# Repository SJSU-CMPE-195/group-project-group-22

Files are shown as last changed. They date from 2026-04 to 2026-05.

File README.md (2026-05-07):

# (Neuromorphic) Hardware Neural Network




Neuromorphic computing replicates brain structure and function directly in hardware. Unlike conventional processors, it uses parallel, event-driven processing for greater efficiency. Software-based spiking neural networks (SNNs) appear in autonomous control systems but carry high energy and resource costs. This project implements the SNN as a real analog circuit — a physical, transistor-level network built from discrete components on a breadboard or PCB — so the hardware itself is the AI player.

The fundamental building block is a **3-neuron control unit** implementing the integrate-and-fire model: an excitatory neuron and an inhibitory neuron both feed into a control (output) neuron. The excitatory neuron drives the control neuron to fire; the inhibitory neuron suppresses overfiring and improves signal stability. Each control unit produces one discrete game action. This scheme is scalable — Hit The Zone uses one 3-neuron control unit (one game input), and Pong uses two control units (six neurons total, one control unit per direction).

An ESP32 microcontroller acts as the analog bridge between the neuron circuit and the game software: it injects stimulus voltage into the excitatory neuron in response to game state, reads the control neuron's output voltage via ADC, and streams real-time voltage data to a Java application over USB serial at 115200 baud. The Java application detects neural spikes via rising-edge analysis and translates each spike one-to-one into a discrete game action.

A **Launcher** manages serial connections and serves as the home page for all programs. Two games are supported: **Hit The Zone** (3-neuron, single-channel) and **Pong** (6-neuron, dual-channel — Ch1 controls left, Ch2 controls right). A **Bidirectional Test** diagnostic tool is also included for verifying serial communication and signal integrity.

## Table of Contents

- [Team](#team)
- [Deliverables](#deliverables)
- [Prerequisites](#prerequisites)
- [Hardware](#hardware)
  - [Hardware Revisions](#hardware-revisions)
  - [Schematic](#schematic)
  - [PCB Design](#pcb-design)
  - [Bill of Materials](#bill-of-materials)
  - [Datasheets](#datasheets)
  - [Breadboard Assembly](#breadboard-assembly)
  - [PCB Assembly](#pcb-assembly)
  - [Flashing the ESP32](#flashing-the-esp32)
- [Running the Application](#running-the-application)
- [Configuration](#configuration)
- [Programs](#programs)
  - [Launcher](#launcher)
  - [Hit The Zone](#hit-the-zone)
  - [Pong](#pong)
  - [Bidirectional Test](#bidirectional-test)
  - [Shared Components](#shared-components)
- [Testing](#testing)
- [Project Structure](#project-structure)
- [License](#license)
- [References](#references)

---

## Team

**Project Number:** U32

**Project Title:** Hardware Neural Network

**Advisor:** Eric Vanuska — eric.vanuska@sjsu.edu

| Name | Degree | GitHub | Email |
|---|---|---|---|
| Jonathon Fleming | BSCMPE | [@JellyF02](https://github.com/JellyF02) | jonathon.fleming@sjsu.edu |
| Raymund Mercader | BSSE | [@ray-sjsu](https://github.com/ray-sjsu) | raymund.mercader@sjsu.edu |
| Andrew Neidhart  | BSCMPE | [@andrewneidhart](https://github.com/andrewneidhart) | andrew.neidhart@sjsu.edu  |
| Katrina Weers | BSSE | [@Trina-W](https://github.com/Trina-W) | katrina.weers@sjsu.edu |

[Spring 2026 CMPE Project Expo](https://www.sjsu.edu/cmpe/students/project-expo/2026-spring.php)

[Spring 2026 CMPE Project Roster](https://docs.google.com/spreadsheets/d/1CWvXRMa2uYdF89KqGeZLIvugnG1znIKHWkJCl6HlvxU/edit?gid=0#gid=0)

---

## Deliverables

The project poster provides a full overview of the hardware design, circuit theory, system architecture, and game demonstrations.

U32 Hardware Neural Network Poster

[Download PDF version](docs/deliverables/U32%20Hardware%20Neural%20Network.pdf)

---

## Prerequisites

**Software:**
- [Java JDK 17](https://docs.oracle.com/en/java/javase/17/install/overview-jdk-installation.html)
- [Arduino IDE](https://www.arduino.cc/en/software) (only needed to flash the ESP32)
- [Apache Maven 3.6+](https://maven.apache.org/install.html) and [Git](https://git-scm.com/install/) (only needed to build from source)

**Hardware:**
- ESP32 microcontroller connected via USB/Serial
- Neural network circuit assembled on breadboard or PCB (see [Hardware](#hardware))

---

## Hardware

### Hardware Revisions

Three physical builds were produced over the course of the project. The Breadboard Big, Breadboard Small, and PCB are functionally identical. See the [project poster](#deliverables) for full hardware design details.

| Revision | Form Factor | Neurons | Notes |
|---|---|---|---|
| Breadboard Big | Full-size breadboard | Up to 6 | Initial large-scale prototype |
| Breadboard Small | Half-size breadboard | Up to 6 | Compact verification build |
| PCB (V2) | Custom KiCad PCB | Up to 6 | Production form factor; functionally identical to all breadboard builds |

| Breadboard Big | Breadboard Small vs. PCB |
|---|---|
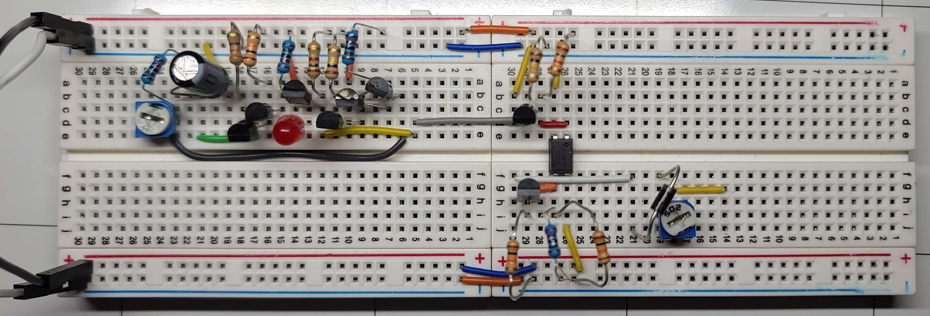
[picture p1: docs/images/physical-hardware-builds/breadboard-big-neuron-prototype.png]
Breadboard Big
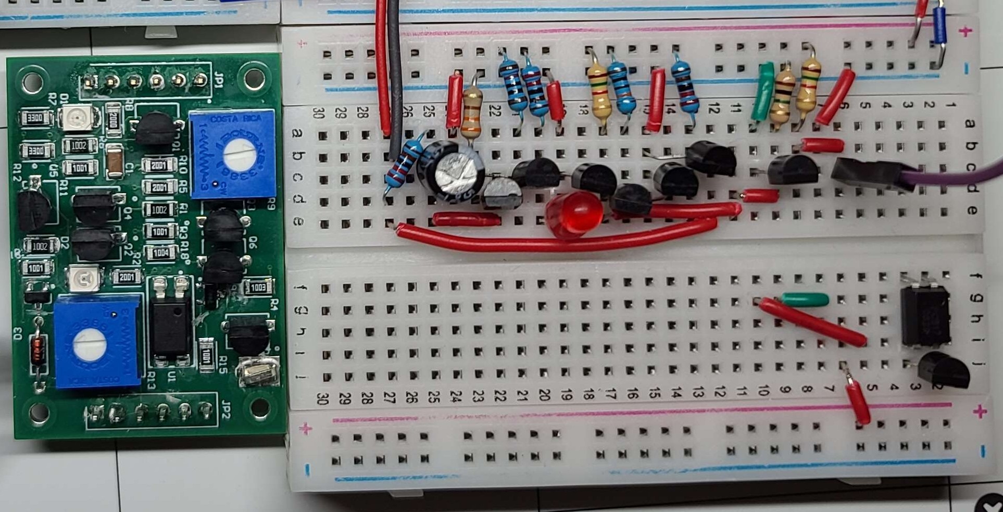
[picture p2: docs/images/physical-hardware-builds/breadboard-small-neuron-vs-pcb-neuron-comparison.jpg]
Breadboard Small vs PCB
|  |  |

| PCB Board | PCB 3D Render |
|---|---|
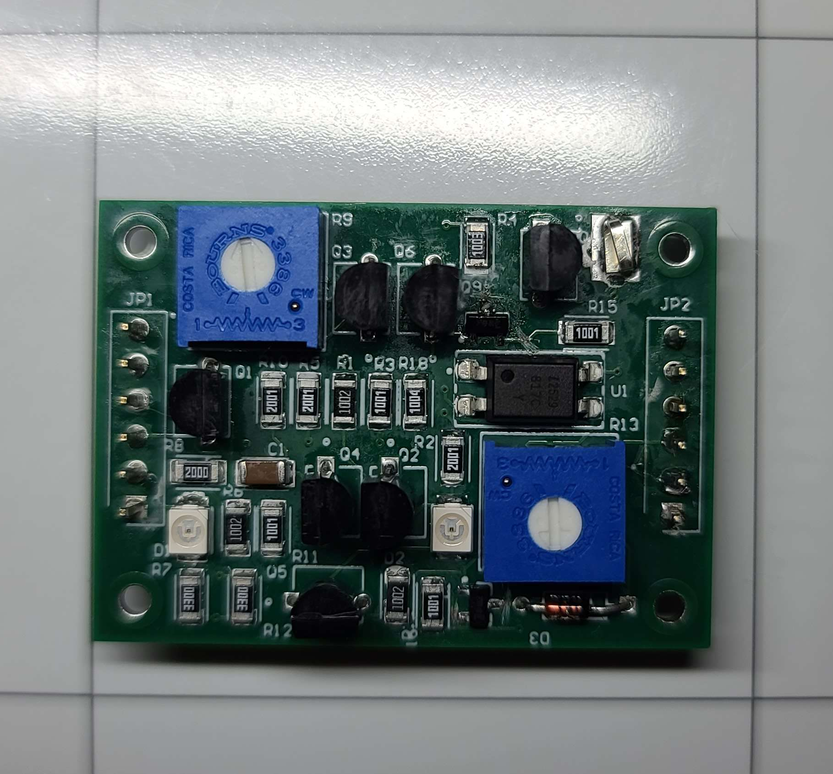
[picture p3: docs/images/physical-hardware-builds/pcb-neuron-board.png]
PCB Board
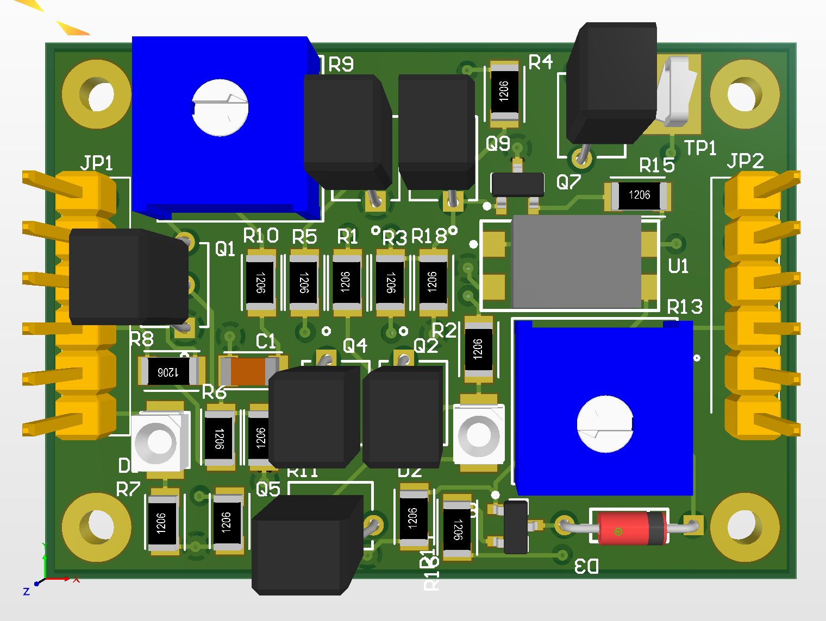
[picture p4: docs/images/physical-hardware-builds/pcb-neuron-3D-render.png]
PCB 3D Render
|  |  |

---

### Schematic

Each neuron in the circuit is built around a **Schmitt trigger** — a comparator with hysteresis. Input voltage charges up slowly (integration), and when it crosses the upper threshold V_UT the output snaps sharply to saturation (the spike). It won't reset until voltage falls below the lower threshold V_LT. The dead band between the two thresholds prevents noise from causing false re-triggers, giving each neuron a clean, stable firing response — directly analogous to a biological action potential [1].

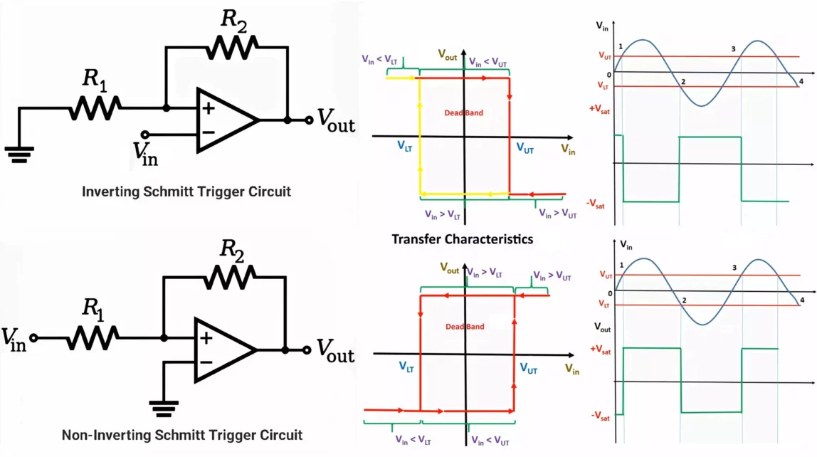
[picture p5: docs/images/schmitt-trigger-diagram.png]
Schmitt Trigger Diagram


**Single Neuron V1** — the initial single-neuron proof-of-concept schematic.

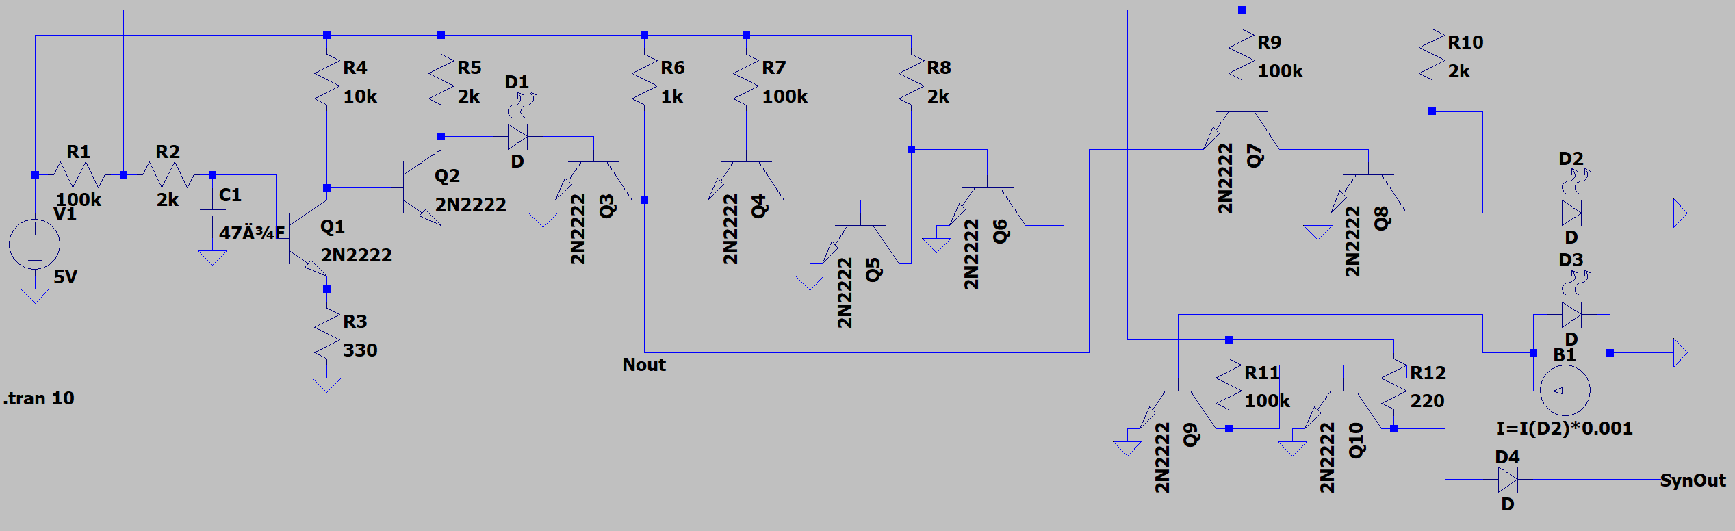
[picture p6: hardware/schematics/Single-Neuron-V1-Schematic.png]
Single Neuron V1 Schematic


Source file: [`hardware/schematics/Single-Neuron-V1-Schematic.asc`](hardware/schematics/Single-Neuron-V1-Schematic.asc) (LTspice)

---

**NeuronSynapseVersion7** — the final 3-neuron design used across all builds.

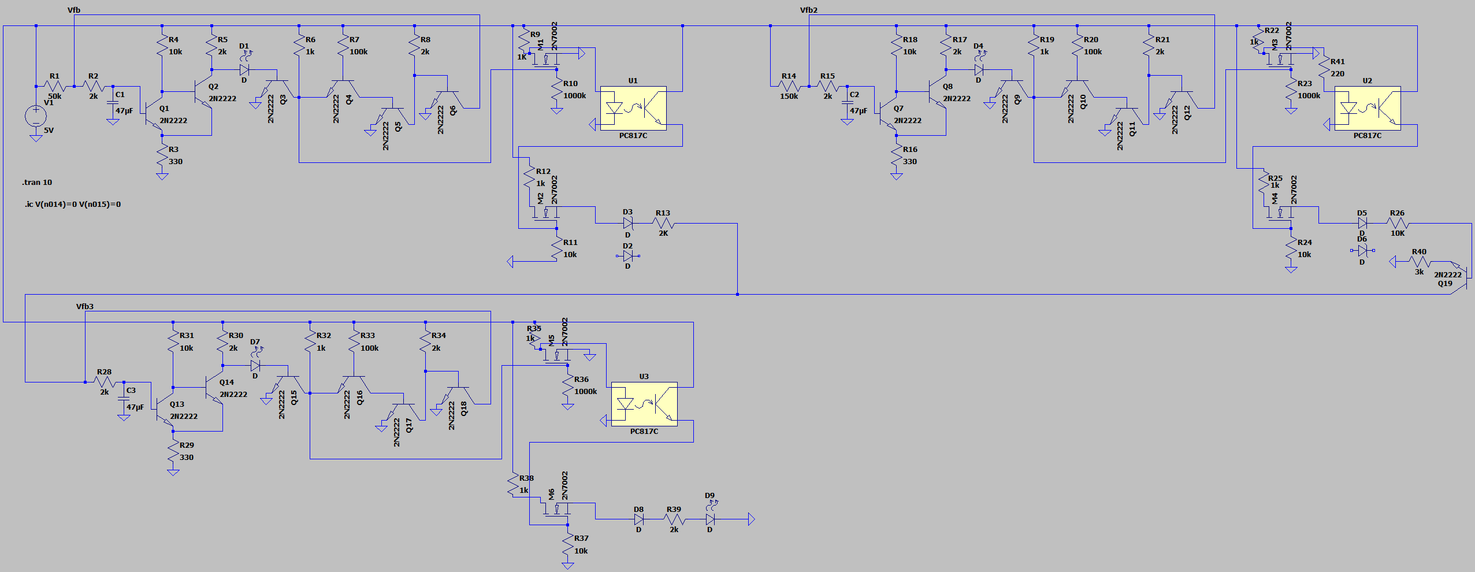
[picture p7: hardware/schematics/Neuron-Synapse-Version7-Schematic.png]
Neuron Synapse Version 7 Schematic


Source files: [`hardware/schematics/Neuron-Synapse-Version7-Schematic.asc`](hardware/schematics/Neuron-Synapse-Version7-Schematic.asc) (LTspice) and [`hardware/schematics/Neuron-Synapse-Version7-Kicad-Schematic.kicad_sch`](hardware/schematics/Neuron-Synapse-Version7-Kicad-Schematic.kicad_sch) (KiCad)

---

### PCB Design

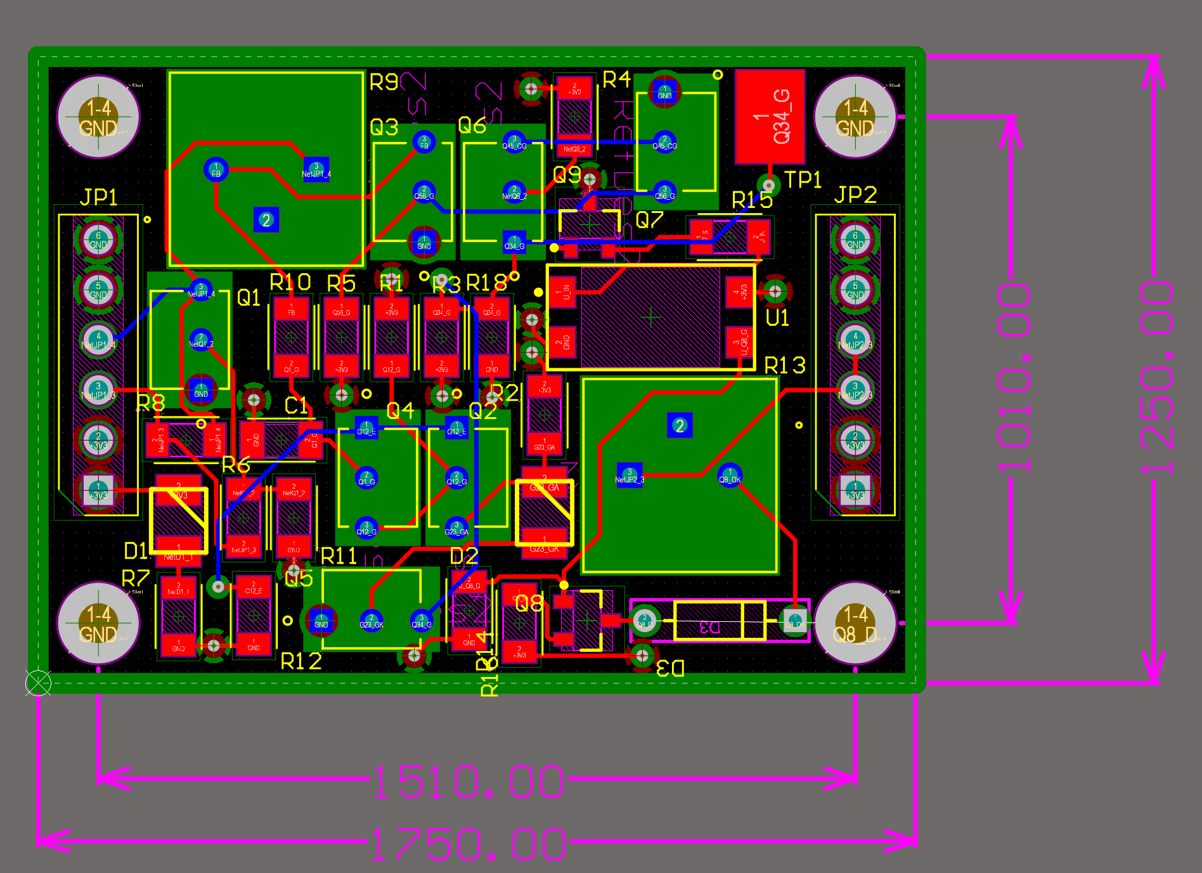
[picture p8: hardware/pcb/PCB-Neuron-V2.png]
PCB V2


KiCad project: [`hardware/pcb/PCB-Neuron-V2-Kicad-Project.kicad_pro`](hardware/pcb/PCB-Neuron-V2-Kicad-Project.kicad_pro)

---

### Bill of Materials

- [`hardware/bom/BOM breadboard.csv`](hardware/bom/BOM_breadboard.csv)
- [`hardware/bom/BOM_pcb.csv`](hardware/bom/BOM_pcb.csv)

---

### Datasheets

- [Espressif ESP32 Datasheet](hardware/datasheets-and-diagrams/Espressif-ESP32-Datasheet.pdf) [2]
- [ESP32 DevKitC Pinout Diagram](hardware/datasheets-and-diagrams/Espressif-ESP32-DevkitC-PinOut-Diagram.png) [3]

---

### Breadboard Assembly

These steps produce a single-channel build for **Hit The Zone**. The Pong extension at the end adds a second circuit for dual-channel support.

You will need the **NeuronSynapseVersion7** schematic (`hardware/schematics/`) open as a reference throughout.

**What you need:**
- Breadboard(s) and jumper wires
- All components listed in [`hardware/bom/BOM_pcb.csv`](hardware/bom/BOM_pcb.csv)
- A breadboard power supply module — powered by a USB battery bank or wall adapter
- An ESP32 microcontroller
- A USB cable to connect the ESP32 to your computer

---

**1. Set up power rails**

Mount the breadboard power supply module onto the breadboard and connect your USB battery bank or wall adapter. Set the output to **3.3V**. Verify that the positive (+) and negative (−) power rails along the breadboard are live before placing any components. The neuron circuit runs on 3.3V.

**2. Gather and place components**

Using the NeuronSynapseVersion7 schematic as your guide, place all components onto the breadboard. The schematic organizes the circuit into three neuron subcircuits — the excitatory neuron, the inhibitory neuron, and the control (output) neuron. Place and wire them one subcircuit at a time to keep the build manageable.

**3. Wire the neuron circuit**

Follow the NeuronSynapseVersion7 schematic section by section. Complete and double-check each subcircuit before moving to the next. Make sure all power and ground connections are secure throughout.

**4. Connect the ESP32**

The ESP32 does not need to sit on the breadboard — it connects to the circuit via jumper wires. Make the following connections (refer to the ESP32 DevKitC pinout [3] to locate these pins):

| ESP32 Pin | Connects to | Purpose |
|---|---|---|
| GPIO34 (ADC6) | Control neuron output node | Reads neuron spike voltage |
| GPIO25 (DAC1) | Excitatory neuron input node | Injects stimulus voltage |
| GND | Breadboard GND rail | Shared ground |

Optionally connect **GPIO2** to a status LED with a current-limiting resistor — the firmware will light it when the neuron output crosses the firing threshold.

Then plug the ESP32 into your computer via USB. This connection is for serial communication only — the breadboard power supply powers the circuit independently.

> **Single-channel build complete.** This is all that is needed to run **Hit The Zone**. Flash the ESP32 with `CHANNEL_COUNT 1` (see [Flashing the ESP32](#flashing-the-esp32)) and proceed to [Running the Application](#running-the-application).

---

**5. Pong extension — add a second control unit**

Pong requires two 3-neuron control units. Build a second complete NeuronSynapseVersion7 circuit on the same or a second breadboard, powered from the same power supply rails. Add the following connections to the ESP32:

| ESP32 Pin | Connects to | Purpose |
|---|---|---|
| GPIO35 (ADC7) | Second control neuron output node | Reads RIGHT spike voltage |
| GPIO26 (DAC2) | Second excitatory neuron input node | Injects RIGHT stimulus voltage |

Flash the ESP32 with `CHANNEL_COUNT 2` (see [Flashing the ESP32](#flashing-the-esp32)) to enable dual-channel mode.

---

### PCB Assembly

The PCB (`hardware/pcb/`) is functionally identical to all breadboard builds in a more compact form factor. Solder components using the NeuronSynapseVersion7 schematic as your reference — component values and connections are the same as the breadboard build.

The PCB has two 6-pin headers, **JP1** (left) and **JP2** (right), which expose power and signal connections. Both headers follow the same pin layout:

| Pin | Net | Purpose |
|-----|---|---|
| 1–2 | `+3V3` | Power supply input (3.3 V) |
| 3–4 | Signal | See below |
| 5–6 | `GND`  | Ground |

- **JP1** (input side) — pin 3 carries the inverted input signal; pin 4 is the direct signal input. Wire **ESP32 GPIO25 (DAC1)** to JP1 pin 4 to inject stimulus voltage.
- **JP2** (output side) — pins 3–4 are bridged on the same net and connect to the control neuron output circuit. Wire **ESP32 GPIO34 (ADC6)** to JP2 pin 3 (or 4) to read the spike voltage.

Power the PCB by connecting a **3.3 V source** to JP1 or JP2 pins 1–2, with **GND** on pins 5–6. The ESP32's onboard 3.3 V output pin can be used for this if the circuit current draw is within limits, or use the same breadboard power supply module approach with a USB battery bank or wall adapter.

---

### Flashing the ESP32

The firmware lives in `hardware/firmware/`. Two `.ino` files are provided — they are functionally identical except for the `CHANNEL_COUNT` parameter:

| `CHANNEL_COUNT` | Configuration | Used by |
|---|---|---|
| `1` | 3-neuron, single ADC channel (GPIO34) | Hit The Zone |
| `2` | 6-neuron, dual ADC channels (GPIO34 + GPIO35) | Pong |

1. Open the desired `.ino` file in **Arduino IDE**:
   - `NeuralSerial_SingleChannel_3Neuron.ino`
   - `NeuralSerial_DualChannel_6Neuron.ino`
2. Confirm or set `CHANNEL_COUNT` near the top of the file:
   ```cpp
   // Set CHANNEL_COUNT to 1 for 3-neuron HitTheZone config.
   // Set CHANNEL_COUNT to 2 for 6-neuron Pong config.
   #define CHANNEL_COUNT 1
   ```
3. Select **Tools → Board → ESP32 Dev Module** and the correct **Tools → Port**.
4. Click **Upload**, then open the **Serial Monitor** at 115200 baud to confirm the board is sending data.

---

## Running the Application

Download the latest release from the [Releases page](https://github.com/SJSU-CMPE-195/group-project-group-22/releases). The release includes the Java application and the ESP32 firmware.

### Java Application

Two distribution formats are available:

**Standalone JAR** — a single `hardware-neural-network.jar` file. Requires Java 17+ already installed on your system.

```bash
java -jar hardware-neural-network.jar
```

**Bundled runtime** — a folder called `hardware-neural-network/` containing a `.exe` alongside `app/` and `runtime/` directories. Java is included — no separate installation needed. Run the `.exe` inside the folder.

This opens the **Launcher**, which is the home page for all programs.

**Building from source** (optional):

```bash
git clone https://github.com/SJSU-CMPE-195/group-project-group-22.git
cd group-project-group-22/software
mvn install
java -jar target/hardware-neural-network.jar
```

### Firmware

The release also includes the `.ino` firmware files for the ESP32. See [Flashing the ESP32](#flashing-the-esp32) for installation instructions.

---

## Configuration

No API keys or environment variables are required. The only configuration is the `CHANNEL_COUNT` firmware parameter described in [Flashing the ESP32](#flashing-the-esp32).

---

## Programs

**Summary Class Diagram**

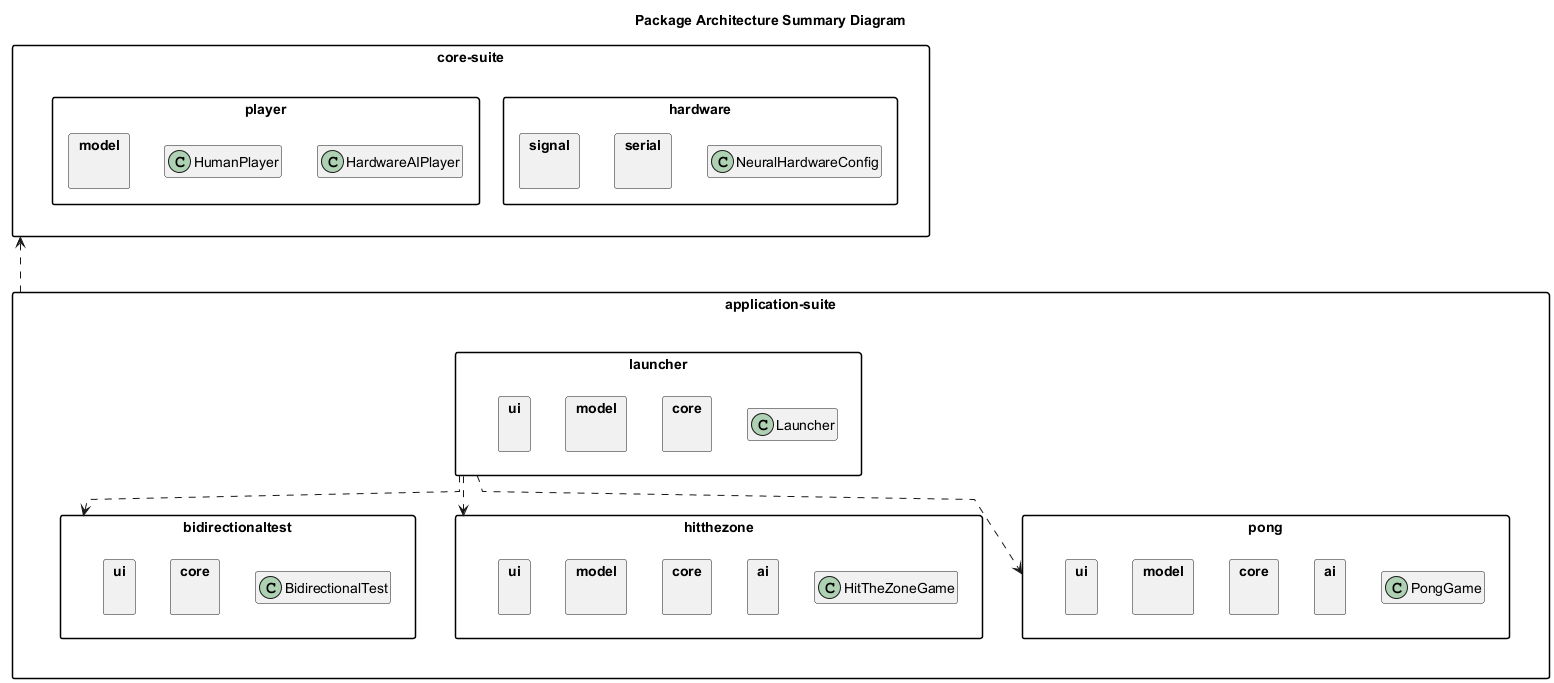
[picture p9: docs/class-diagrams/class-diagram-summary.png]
Summary Class Diagram


---

### Launcher

The Launcher is the home page of the application. It provides two serial connection panels — one for Hit The Zone (single-channel) and one for Pong (dual-channel) — and buttons to open each program.

Connect your ESP32 device(s) in the Launcher before opening a program to enable the hardware neural network AI player. All programs are fully playable without hardware — Software AI players serve as the baseline for comparison, and the Hardware AI option will simply be grayed out when no device is connected.

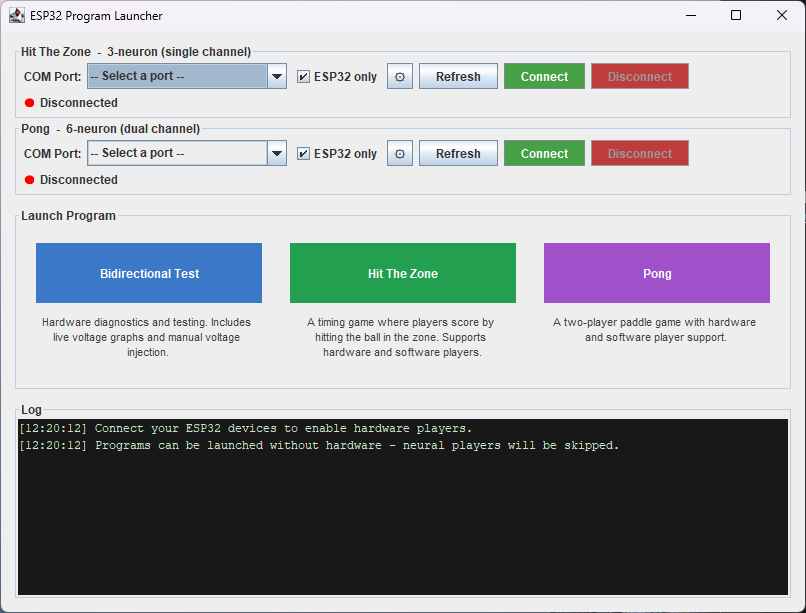
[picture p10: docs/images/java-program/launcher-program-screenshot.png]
Launcher


**Class Diagram**

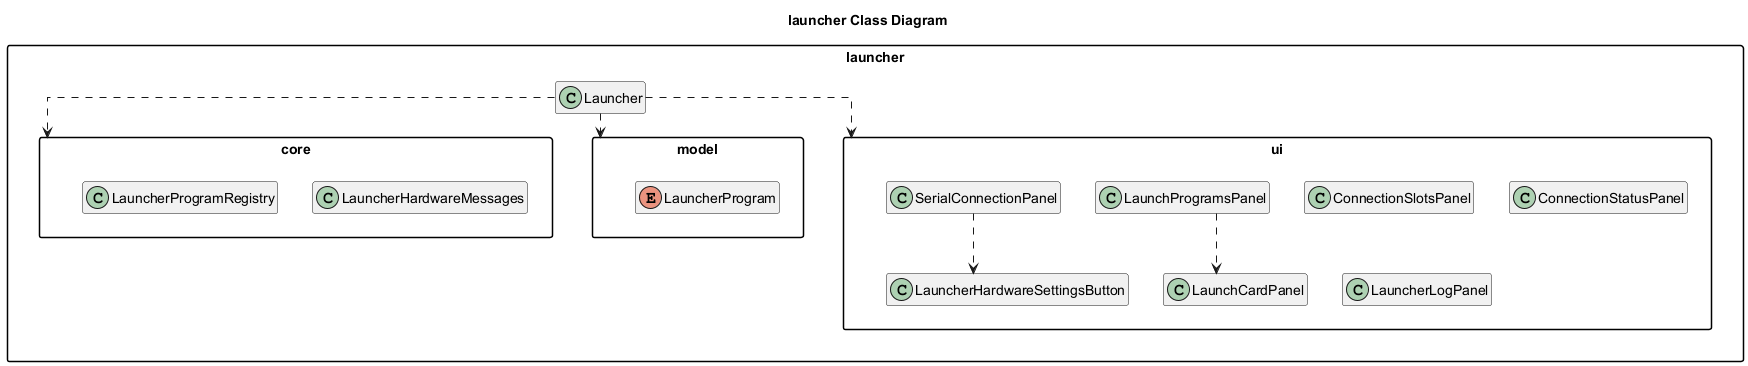
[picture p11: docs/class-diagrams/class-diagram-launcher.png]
Launcher Class Diagram


---

### Hit The Zone

A game where four players take turns hitting a ball as it passes through a target zone. The hardware SNN (using the 3-neuron, single-channel ESP32 firmware config) competes alongside two software AI bots and a human player.

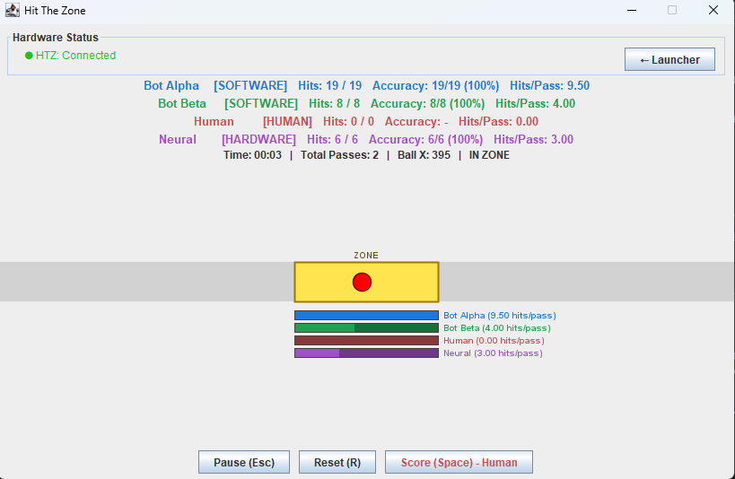
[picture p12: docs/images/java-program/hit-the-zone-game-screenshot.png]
Hit The Zone


**Hardware Setup**

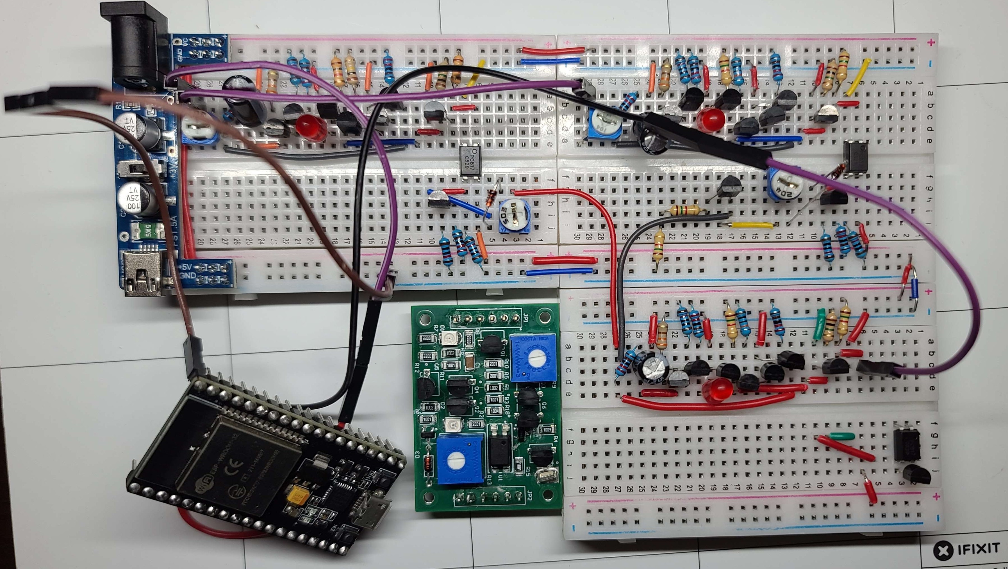
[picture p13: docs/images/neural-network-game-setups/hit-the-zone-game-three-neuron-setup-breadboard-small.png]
Hit The Zone — 3-Neuron Setup (Breadboard Small)


**Players:**
- **Bot Alpha / Beta** — software AI players
- **Human** — press Space when the ball is inside the yellow zone to score a hit
- **Neural** — the ESP32 hardware neural network player

**Controls:**

| Key | Action |
|---|---|
| Space | Hit the ball (when inside zone) |
| Esc | Pause / unpause |
| R | Reset the game |

**Stats tracked:** Hits (successful / total attempts), Accuracy (%), Hits/Pass (average hits per ball pass)

**Class Diagram**

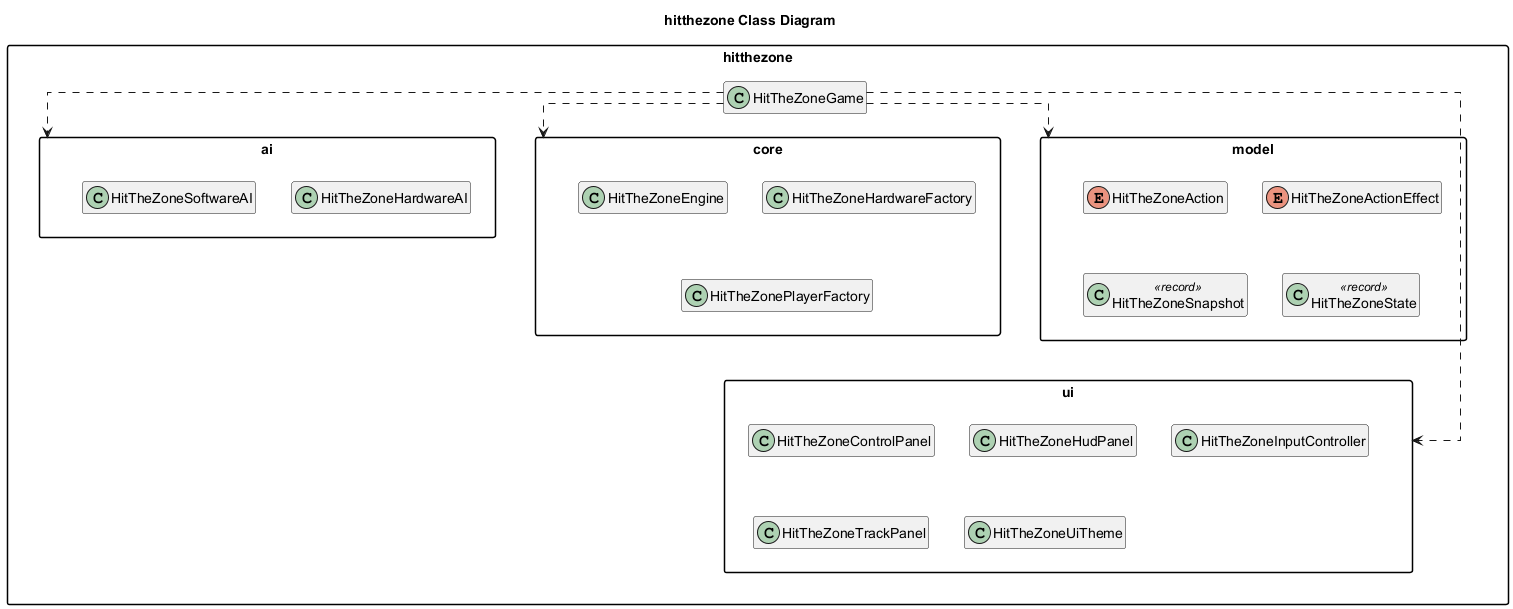
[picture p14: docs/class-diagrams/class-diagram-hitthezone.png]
Hit The Zone Class Diagram


---

### Pong

A Pong game where the hardware SNN competes as an AI paddle controller. The ESP32 (6-neuron, dual-channel config) reads two ADC channels — GPIO34 for LEFT and GPIO35 for RIGHT — and drives a single hardware AI player. Player types (Human / Hardware AI / Software AI Easy / Software AI Hard) are selected from the in-game toolbar.

**SNN Architecture**

Pong uses two 3-neuron control units (6 neurons total). Each control unit consists of an excitatory neuron, an inhibitory neuron, and a control (output) neuron — both the excitatory and inhibitory neurons feed into the control neuron, which fires when its membrane voltage V reaches threshold θ. One control unit drives LEFT, the other drives RIGHT.

The architecture diagram below shows the logical view: Ball X Position feeds a Directional Split Layer (Ball Left / Ball Right excitatory neurons), which drive an Output Layer (Paddle Left / Paddle Right control neurons). The red cross-inhibition connections — Ball Left inhibiting Paddle Right and vice versa — represent the inhibitory neurons in each control unit, ensuring only one direction fires at a time, producing one discrete paddle movement event per spike.

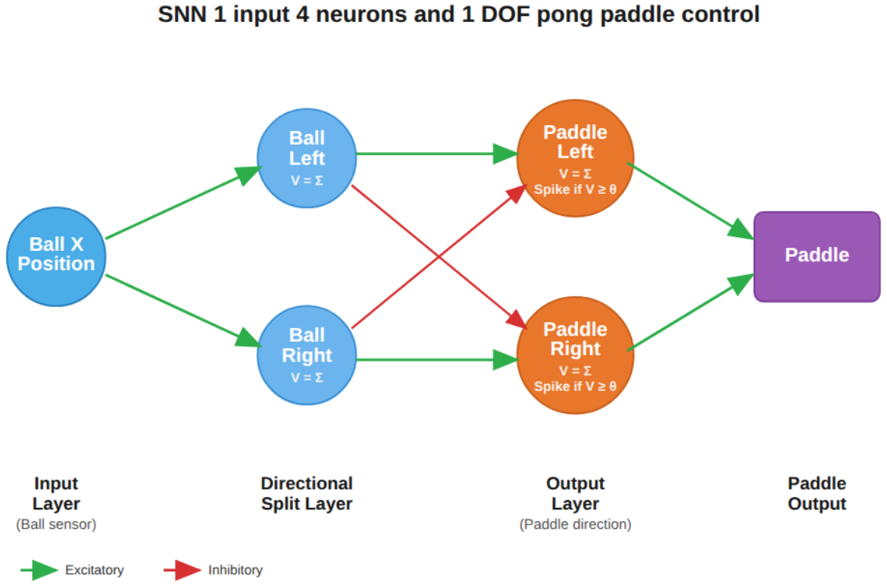
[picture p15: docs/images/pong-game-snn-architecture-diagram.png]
Pong SNN Architecture Diagram


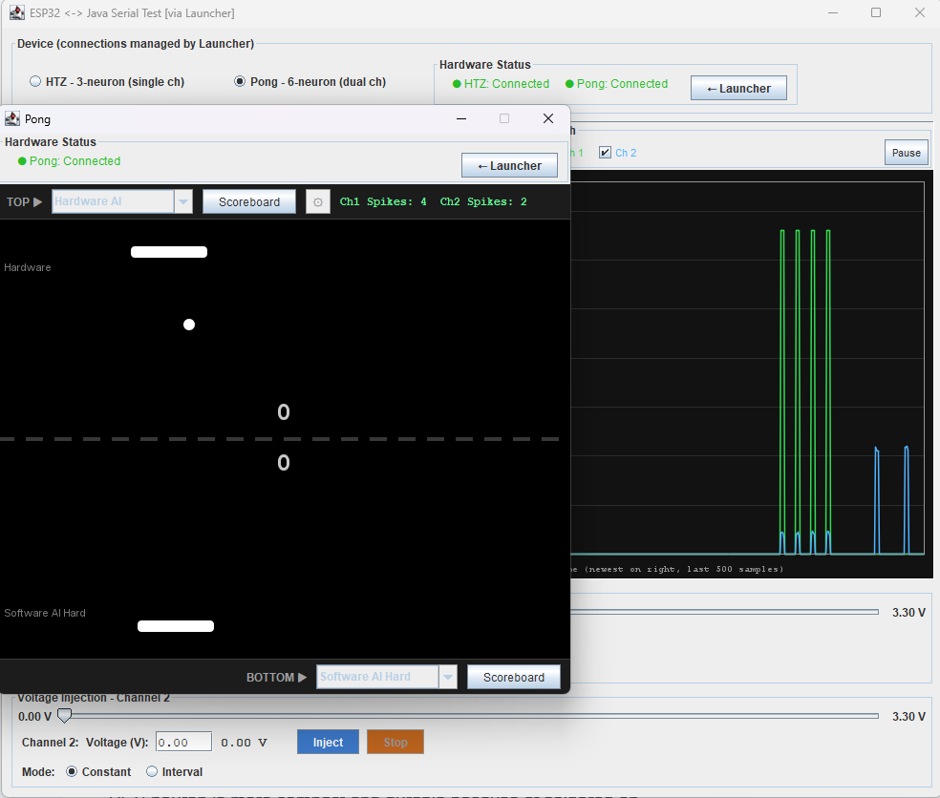
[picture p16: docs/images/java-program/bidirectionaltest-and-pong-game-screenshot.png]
Pong


**Hardware Setup**

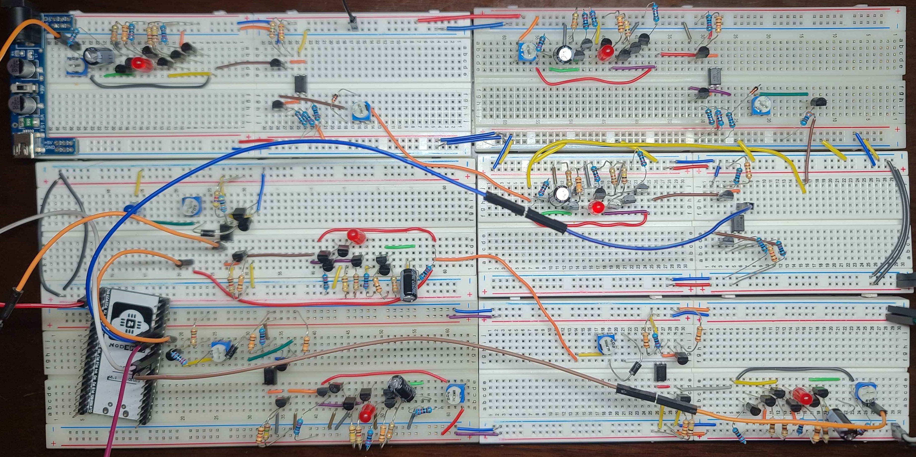
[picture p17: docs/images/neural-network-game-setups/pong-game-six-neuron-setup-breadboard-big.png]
Pong 6-Neuron Setup (Breadboard Big)


**Controls (Human player):**

| Key | Action |
|---|---|
| ← / → | Move paddle left / right |
| Esc | Pause / unpause |
| R | Reset the game (from pause menu) |
| C | Toggle constant ball speed (from pause menu) |
| 1 / 2 / 3 | Select ball speed level (from pause menu) |

**Class Diagram**

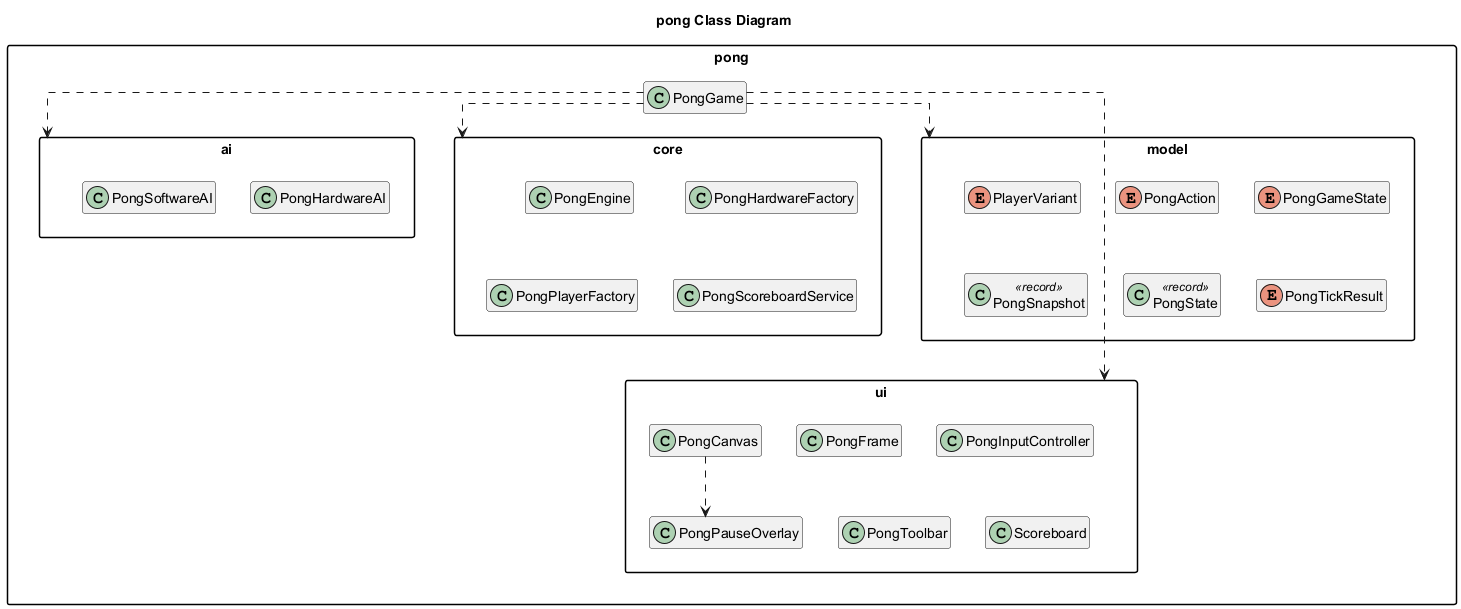
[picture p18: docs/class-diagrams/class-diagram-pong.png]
Pong Class Diagram


---

### Bidirectional Test

A diagnostic tool for verifying serial communication between the ESP32 and the Java application. It receives both Launcher-managed connections (Hit The Zone and Pong) and lets you switch between them to inspect bidirectional data flow — useful for debugging firmware behavior or confirming signal integrity before running a game.

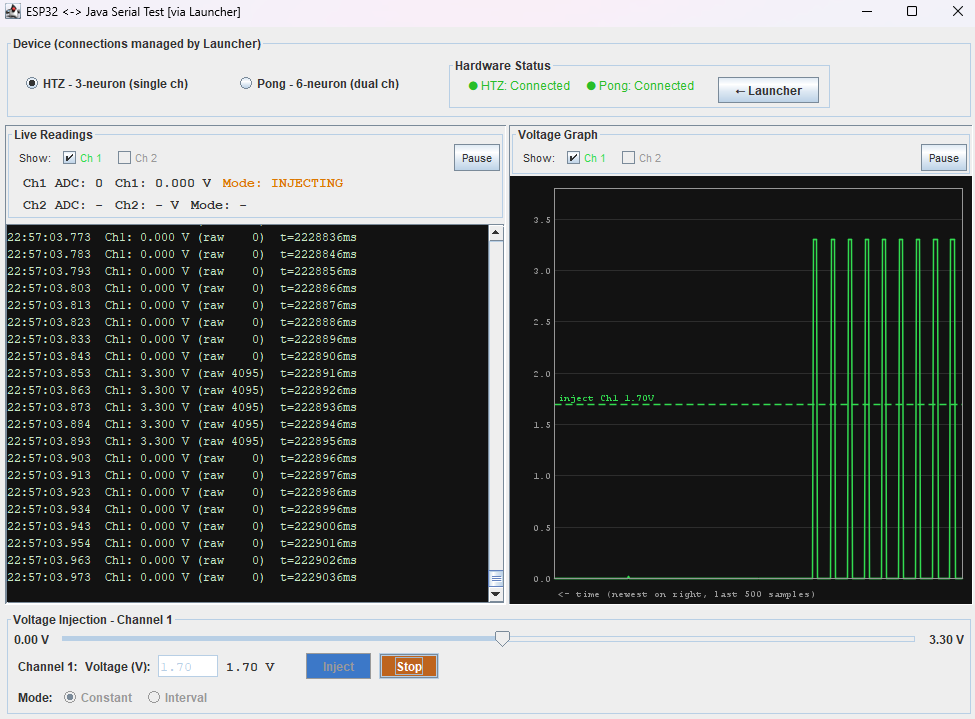
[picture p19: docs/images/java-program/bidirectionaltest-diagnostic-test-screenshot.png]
Bidirectional Test


**Class Diagram**

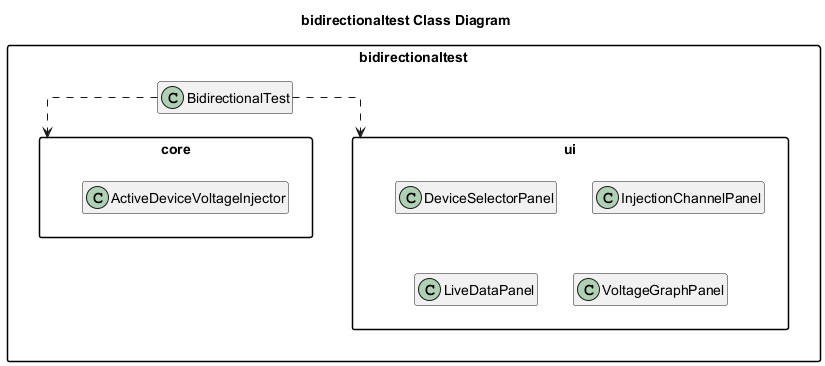
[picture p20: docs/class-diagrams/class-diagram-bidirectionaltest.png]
Bidirectional Test Class Diagram


---

### Shared Components

The `hardware` and `player` packages are shared across all programs. `hardware` handles serial connection management and neural signal processing. `player` provides the base player abstractions used by every game.

**Hardware Class Diagram**

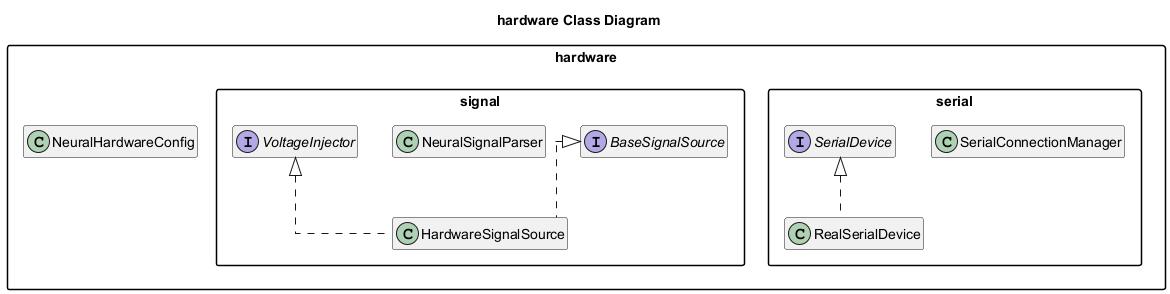
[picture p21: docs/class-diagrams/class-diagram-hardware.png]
Hardware Class Diagram


**Player Class Diagram**

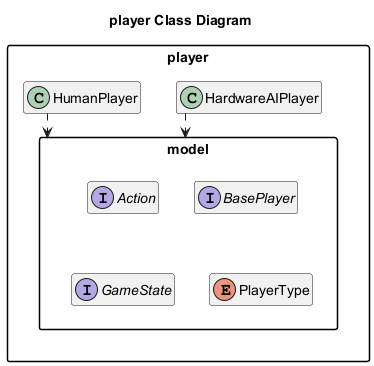
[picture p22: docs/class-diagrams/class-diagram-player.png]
Player Class Diagram


---

## Testing

### Running the Test Suite

```bash
cd software
mvn verify
```

This runs all unit, integration, and stress tests and generates a JaCoCo HTML coverage report at `software/target/site/jacoco/index.html`.

> Tests that instantiate Swing components require a display. On Linux, prefix with `xvfb-run --auto-servernum`.

**Useful variants:**

```bash
# Stress tests only (no display required)
mvn test -Dgroups=stress

# A single test class
mvn test -Dtest=NeuralSignalParserTest
```

### Coverage

The latest coverage report is uploaded as the **`jacoco-coverage-report`** artifact on every CI run — see [Actions](https://github.com/SJSU-CMPE-195/group-project-group-22/actions/workflows/ci.yml).

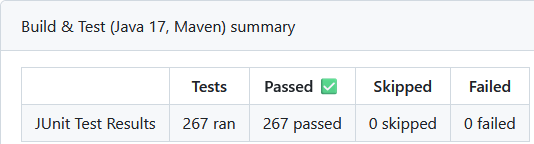
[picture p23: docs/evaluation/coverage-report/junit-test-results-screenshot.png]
JUnit Test Results


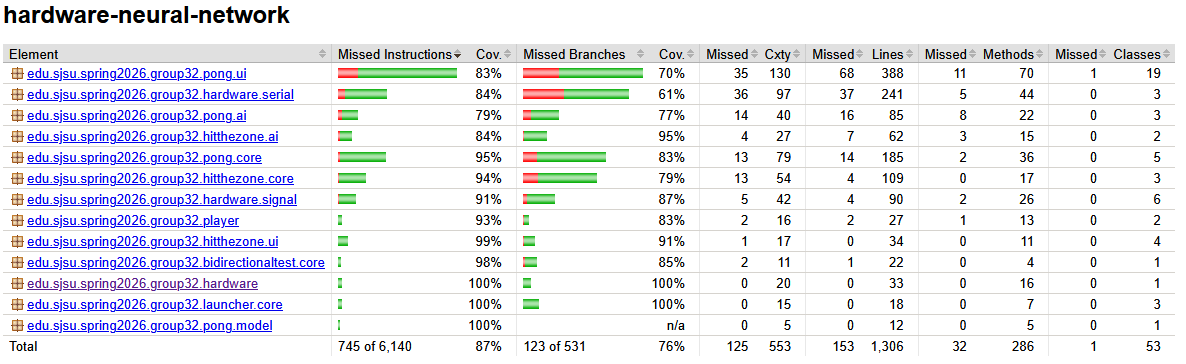
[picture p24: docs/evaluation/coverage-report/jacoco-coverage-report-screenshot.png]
JaCoCo Coverage Report


Full coverage details, per-package breakdown, and exclusion rationale are in [`docs/evaluation/coverage-report/README.md`](docs/evaluation/coverage-report/README.md).

### Stress Test Results

Documented in [`docs/evaluation/stress-test-results.md`](docs/evaluation/stress-test-results.md).

---

## Project Structure

```
group-project-group-22/
├── .github/
│   └── workflows/
│       └── ci.yml                                  # Build, test, and coverage reporting
├── docs/
│   ├── class-diagrams/                             # PNG class diagrams
│   │   ├── plantuml-diagrams/                      # PlantUML source (.puml)
│   │   ├── class-diagram-bidirectionaltest.png
│   │   ├── class-diagram-hardware.png
│   │   ├── class-diagram-hitthezone.png
│   │   ├── class-diagram-launcher.png
│   │   ├── class-diagram-player.png
│   │   ├── class-diagram-pong.png
│   │   └── class-diagram-summary.png
│   ├── deliverables/                               # Project poster (SVG + PDF)
│   ├── evaluation/                                 # coverage-report/ + stress-test-results.md
│   └── images/
│       ├── java-program/                           # Application screenshots
│       ├── neural-network-game-setups/             # Hardware + game configuration photos
│       ├── physical-hardware-builds/               # Build photos (breadboard, PCB)
│       ├── pong-game-snn-architecture-diagram.png
│       └── schmitt-trigger-diagram.png
├── hardware/
│   ├── bom/                                        # Bill of materials (CSV)
│   ├── datasheets-and-diagrams/                    # ESP32 datasheet and pinout diagram
│   ├── firmware/                                   # ESP32 Arduino firmware (single- and dual-channel) + archive/
│   ├── pcb/                                        # KiCad PCB V2 project + archive/
│   └── schematics/                                 # KiCad + LTspice schematics, PNGs + archive/
├── scripts/
│   └── generate-class-diagram.py                   # Generates PlantUML source from Java source
├── software/
│   └── src/
│       ├── main/java/.../
│       │   ├── bidirectionaltest/                  # Diagnostic tool — core/ + ui/
│       │   ├── hardware/                           # Serial + signal processing — serial/ + signal/
│       │   ├── hitthezone/                         # Hit The Zone game — ai/ + core/ + model/ + ui/
│       │   ├── launcher/                           # Launcher home page — core/ + model/ + ui/
│       │   ├── player/                             # Shared player abstractions — model/
│       │   └── pong/                               # Pong game — ai/ + core/ + model/ + ui/
│       └── test/java/.../                          # JUnit 5 + Mockito test suite + stress/ + testsupport/
├── tests/
│   └── README.md                                   # Test structure and instructions
├── .gitignore
├── LICENSE
├── README.md
├── SCHEDULE-195.md
├── icon.ico
└── pom.xml
```

---

## License

This project is licensed under the MIT License — see the [`LICENSE`](LICENSE) file for details.

> Distribution is subject to applicable San Jose State University intellectual property policies.
---

## References

[1] Hackatronic, "Schmitt Trigger Circuit Diagram, Working, Types & Applications," *Hackatronic*, 2023. [Online]. Available: https://www.hackatronic.com/schmitt-trigger-circuit-diagram-working-types-applications/. [Accessed: May 6, 2026].

[2] Espressif Systems, "ESP32 Series Datasheet," *Espressif Systems*, 2024. [Online]. Available: https://documentation.espressif.com/esp32_datasheet_en.pdf. [Accessed: May 6, 2026].

[3] Espressif Systems, "ESP32-DevKitC User Guide," *Espressif Documentation*, 2024. [Online]. Available: https://docs.espressif.com/projects/esp-dev-kits/en/latest/esp32/esp32-devkitc/user_guide.html. [Accessed: May 6, 2026].

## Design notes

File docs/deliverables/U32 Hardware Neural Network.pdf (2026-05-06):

TEMPLATE DESIGN © 2008
www.PosterPresentations.com

Figure 3 - Breadboard layout

Wabiszewski, C. (2025, July 26). Artificial Brain Controlled RC Truck - Global Science Network. Retrieved from Global Science Network website:
https://www.gsnetwork.com/artificial-brain-controlled-rc-truck/

Justesen, N., Bontrager, P., Togelius, J., & Risi, S. (2020). Deep learning for video game playing. IEEE Transactions on Games, 12(1), 1–20. doi:10.1109/tg.2019.2896986

Patel, D., Hazan, H., Saunders, D. J., Siegelmann, H. T., & Kozma, R. (2019). Improved robustness of reinforcement learning policies upon conversion to spiking neuronal network platforms applied to Atari Breakout Game. Neural Networks, 120, 108–115. doi:10.1016/j.neunet.2019.08.009

Shaban, A., Bezugam, S. S., & Suri, M. (2021). An adaptive threshold neuron for recurrent spiking neural networks with nanodevice hardware implementation. Nature Communications, 12(1). doi:10.1038/s41467-021-24427-8

Hardware and Software Testing
- Software was validated using JUnit, Mockito, JaCoCo achieving 80% code coverage.
- Software correctly interprets spike events and are converted one-to-one with game actions.
- Hardware verification included a function generator, power supply, and oscilloscope confirming stable neuron firing, and tuning via potentiometers.
- Stress tests passed while handling repeated disconnect/reconnect events.

# U32 - (Neuromorphic) Hardware Neural Network

## Project Advisor: Eric Vanuska

Neuromorphic computing replicates brain structure and function directly in hardware. Unlike conventional processors, it uses parallel, event-driven processing for greater efficiency. Software-based spiking neural networks (SNN) are a big player in autonomous control systems, but they carry high energy and resource costs.

Methodology

Analysis and Results

Summary/Conclusions

Key References

Acknowledgements

The project successfully demonstrated that a small-scale SNN built from analog components can control a system in real-time. The SNN tracked ball position and generated movement commands without any traditional processor or software-based interface involved in the decision-making. By bridging the neuron circuits with a Java game environment through ESP32, we showed that neuromorphic hardware can interface with conventional software systems using a simple microcontroller. The modular PCB layout allows for future expansion to larger and more complex designs.

The team would like to thank Jason Skender for expertise and guidance throughout the PCB design process.

We would also like to extend our gratitude towards our advisor Eric Vanuska for assistance and helping us communicate our technical work to be more accessible to a broader audience.

Initial steps included creating a single neuron simulation in LTspice (Figure 2) for design verification followed by simulating two more, an inhibitory and control neuron. From there, we validated the design with a physical breadboard neuron, proving we could replicate the expected spiking behavior before committing to a printed circuit board (PCB) layout.

Following the initial validation, we
expanded the breadboard circuit to a 3-neural network. After hardware verification, breadboard schematic converted into custom PCB layout (Altium Designer). The project culminated in printing and physical assembly of our final PCB, translating the integrated and fire model into a robust, tileable device.
- System is split into two subsystems: an analog neuromorphic hardware SNN and a software game environment, bridged by an ESP32 microcontroller.
- The neuron circuits receive voltage signals from the game and fire after the charge hits a set threshold.
- The resulting voltage spikes pass through the synapse circuit which are read by the ESP32 and sent via universal asynchronous receiver-transmitter (UART) as game actions.

Hardware
A basic control unit requires a 3-neural network: a control neuron, an inhibitory neuron, and excitatory neuron. A control unit represents one game action.

In Figure 6, a breadboard 3-neural network is shown:
- ESP32 injects stimulus into the excitatory neuron encouraging the control neuron to fire.
- Inhibitory neuron modulates the control neuron to suppress overfiring and improve signal stability of the control neuron.
- Read by the ESP32, the control neuron acts as the final integrated output of both the inhibitory and excitatory neurons.
This control unit scheme is scalable up to many game inputs. HitTheZone, a 3-neural network, supports one game input. Meanwhile, Pong is a 6-neuron network with two 3-neuron networks to supports up to two inputs.
The breadboard and PCB neuron are functionally identical, but the PCB neuron is more compact and durable because of soldered on components compared to loosely mounted components on a breadboard. For demo purposes, the breadboard version better showcases individual components.

# Computer Engineering Department

Software
Software includes ESP32 firmware and a software Java program with many subprograms.
- ESP32 .ino firmware (Single and dual channel)
- Java program Launcher
- Java game HitTheZone (3-neural network)
- Java game Pong (6-neural network)
- Java diagnostic tool BidirectionalTest ESP32 firmware is written in Ardurino and delivers the stimulus to the excitatory neuron, read the control neuron’s response and return output as real-time voltage. Java program is able to read discrete spikes and translate each spike into one discrete game event. In Figure 7, Pong game, controlled by a 6-neural network. Two control units (3-neural networks, Ch1 and Ch2) control left and right paddle movements respectively.

### Fleming, Jonathon (BS Computer Engineering) Mercader, Raymund (BS Software Engineering)

Neidhart, Andrew | (BS Computer Engineering)
Weers, Katrina | (BS Software Engineering)

Introduction

Figure 5 - Hardware and Software System High-Level Overview

Figure 6 - Breadboard 3-neural network (HitTheZone) For scale reference, one PCB neuron is shown

Figure 1 - Network Architecture Digram

Figure 2 - Single neuron spice simulation

Figure 4 - PCB layout

Figure 7 - Pong game overlaid over BIdirectionalTestTool showing spke-based paddle control. Ch1 controls left and Ch2 controls right. One spike equals one game (paddle) event.

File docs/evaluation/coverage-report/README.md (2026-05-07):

# Code Coverage Report

JaCoCo generates an HTML coverage report during every `mvn verify` run.

## Latest Results (May 2026)

### JUnit Test Results

JUnit Test Results

267 tests ran — **267 passed, 0 skipped, 0 failed**.

### JaCoCo Coverage Report

JaCoCo Coverage Report

| Counter | Result |
|---|---|
| Instruction coverage | **87%** (745 of 6,140 missed) |
| Branch coverage | **76%** (123 of 531 missed) |
| Line coverage | **88%** (153 of 1,306 missed) |
| Method coverage | **89%** (32 of 286 missed) |
| Class coverage | **98%** (1 of 53 missed) |

#### Per-Package Breakdown

| Package | Instruction Cov. | Branch Cov. |
|---|---|---|
| `pong.ui` | 83% | 70% |
| `hardware.serial` | 84% | 61% |
| `pong.ai` | 79% | 77% |
| `hitthezone.ai` | 84% | 95% |
| `pong.core` | 95% | 83% |
| `hitthezone.core` | 94% | 79% |
| `hardware.signal` | 91% | 87% |
| `player` | 93% | 83% |
| `hitthezone.ui` | 99% | 91% |
| `bidirectionaltest.core` | 98% | 85% |
| `hardware` | 100% | 100% |
| `launcher.core` | 100% | 100% |
| `pong.model` | 100% | n/a |

## Viewing the Report

### Locally

```bash
cd software
mvn verify
open target/site/jacoco/index.html          # macOS
xdg-open target/site/jacoco/index.html      # Linux
start target/site/jacoco/index.html         # Windows
```

### From GitHub Actions (CI)

1. Go to the [CI workflow runs](https://github.com/SJSU-CMPE-195/group-project-group-22/actions/workflows/ci.yml).
2. Open the most recent successful run.
3. Scroll to **Artifacts** and download `jacoco-coverage-report`.
4. Unzip and open `index.html` in a browser.

## Coverage Exclusions

The following classes are excluded from coverage metrics (see `pom.xml`):

| Category | Classes excluded |
|---|---|
| Swing JFrame/JPanel shells | `Launcher`, `HitTheZoneGame`, `PongGame`, `PongFrame`, all of `launcher/ui/*`, `BidirectionalTest`, all of `bidirectionaltest/ui/*`, `HitTheZoneHudPanel`, `HitTheZoneTrackPanel`, `HitTheZoneControlPanel` |
| Hardware adapter | `RealSerialDevice` |
| Enums / models | `PlayerType`, `LauncherProgram`, `PongAction`, `PongGameState`, `PongSnapshot`, `PongState`, `PongTickResult`, `HitTheZoneAction`, `HitTheZoneActionEffect`, `HitTheZoneSnapshot`, `HitTheZoneState` |
| Coverage annotation | `GeneratedExcludeFromCoverage` |

These are excluded because they consist entirely of auto-generated, hardware-dependent, Swing-layout-only, or data-only value types that cannot be meaningfully exercised at unit level.

## Coverage Targets

| Counter | Target | Current | Enforced minimum |
|---|---|---|---|
| Instruction coverage | 80%+ | ✅ 87% | 80% (enforced via `jacoco-check` in `pom.xml`) |
| Branch coverage (core functionality) | 70%+ | ✅ 76% | none |

> **Note on `pong.ai`:** Instruction coverage for `pong.ai` is 79%, just below the 80% instruction target. The remaining gap is in AI edge-case branches that require hardware simulation to exercise fully.

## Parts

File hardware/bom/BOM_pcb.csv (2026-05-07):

Line # | Name | Description | Designator | Quantity | Manufacturer 1 | Manufacturer Part Number 1 | Manufacturer Lifecycle 1 | Supplier 1 | Supplier Part Number 1 | Supplier Unit Price 1 | Supplier Subtotal 1
 | 2n2222a | Bipolar (BJT) Transistor NPN 40 V 600 mA 250MHz 625 mW Through Hole TO-92 | Q1, Q2, Q3, Q4, Q5, Q6, Q7 | 7
 | Bourns 3386P-1-104LF | 100 kOhms 0.5W, 1/2W PC Pins Through Hole Trimmer Potentiometer Cermet 1.0 Turn Top Adjustment | R9 | 1
 | 1k | 1K OHM 1% 1/4W 1206 | R3, R11, R14, R15 | 4 | Panasonic | ERJ-8ENF1001V | Not Recommended for New Design | Mouser | 667-ERJ-8ENF1001V | 0.054 | 0.54
 | 100k | 100K OHM 1% 1/4W 1206 | R4 | 1 | Panasonic | ERJ-8ENF1003V | Not Recommended for New Design | DigiKey | P100KFCT-ND | 0.16 | 0.16
 | 330 | 330 OHM 1% 1/4W 1206 | R7, R12 | 2 | Panasonic | ERJ-8ENF3300V | Not Recommended for New Design | DigiKey | P330FCT-ND | 0.16 | 0.32
 | ERJ-8ENF2000V | 200 OHM 1% 1/4W 1206 | R8 | 1 | Panasonic | ERJ-8ENF2000V | Not Recommended for New Design | DigiKey | P200FCT-ND | 0.16 | 0.16
 | ERJ-8ENF2001V | 2K OHM 1% 1/4W 1206 | R2, R5, R10 | 3 | Panasonic | ERJ-8ENF2001V | Not Recommended for New Design | Mouser | 667-ERJ-8ENF2001V | 0.16 | 0.48
 | ERJ-8ENF1004V | 1M OHM 1% 1/4W 1206 | R18 | 1 | Panasonic | ERJ-8ENF1004V | Unknown
 | HEADER_6X1 | HEADER VERT 6POS .100 TIN | JP1, JP2 | 2 | Wurth Elektronik | 61300611121 | Unknown | Mouser | 710-61300611121 | 0.34 | 0.68
 | 1N4148WT | Rectifier Diode, 1 Phase, 1 Element, 0.15A, 100V V(RRM), Silicon | D3 | 1 | onsemi | 1N4148TR | Volume Production | Mouser | 512-1N4148TR | 0.1 | 0.1
 | 2N7002 | MOSFET N-CH 60V 115 mA | Q8, Q9 | 2 | onsemi | 2N7002 | Volume Production | Mouser | 512-2N7002 | 0.59 | 1.18
 | 3386P-1-504LF | Cermet Not Linear VERTICAL Trimmer Potentiometer ?10% 280deg 500mW 85C | R13 | 1 | Bourns | 3386P-1-504LF | Volume Production | Mouser | 652-3386P-1-504LF | 1.22 | 1.22
 | 5016 | PC TEST POINT COMPACT SMT | TP1 | 1 | Keystone | 5016 | Volume Production | DigiKey | 36-5016CT-ND | 0.26 | 0.26
 | AA3528SESK/J3 | LED Red 2.2V 20mA | D1, D2 | 2 | Kingbright | AA3528SESK/J3 | Volume Production | DigiKey | 754-1771-1-ND | 0.54 | 1.08
 | C3216X5R1E476M160AC | CER 47uF 25V X5R 1206 2.082mOhm | C1 | 1 | TDK | C3216X5R1E476M160AC | Volume Production | DigiKey | 445-8047-1-ND | 0.89 | 0.89
 | LTV-817S | LTV Series Single Channel 35 V 5000 Vrms Transistor Output Optocoupler SMT-DIP-4 | U1 | 1 | Lite-On | LTV-817S | Volume Production | Mouser | 859-LTV-817S | 0.26 | 0.26
 | RNCF1206TKY10K0 | RES 10K OHM 0.01% 1/4W 1206 | R1, R6, R16 | 3 | Stackpole Electronics | RNCF1206TKY10K0 | Volume Production | Mouser | 708-RNCF1206TKY10K0 | 1.65 | 4.95

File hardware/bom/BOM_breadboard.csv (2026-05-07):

Name | Description | Quantity | Manufacturer 1 | Supplier 1 | Supplier Unit Price 1
BOJACK 2N2222 | NPN 60V 0.8A 0.5W 250MHZ Power General Purpose Transistors (Pack of 200) | 1 | BOJACK | Amazon | $6.99
Rubycon 47uF 50V | 6.3x11mm Electrolytic Capacitor Low ESR 0.3Ω Long Life Radial Lead (Pack of 15) | 1 | Rubycon | Amazon | $6.49
Bridgold 2N7000 | N-Channel Enhancement Mode Field Effect Transistor 60V 20mA TO-92 (100pcs) | 1 | Bridgold | Amazon | $6.99
1000 PCS Resistor Kit | 1/4 W +-1% Premium Metal Film Resistors Assortment Kit 25 Values | 1 |  | Amazon | $5.79
California JOS 5mm LED | 50 PCS Colorful Light Diodes Assorted Kit | 1 | California JOS | Amazon | $4.59
DEYUE Breadboard Set | 6 PCS 400 Pin Solderless Prototype Board Kit | 1 | DEYUE | Amazon | $7.99
BOJACK Potentiometer Kit | 15 Values 150 pcs 100 Ohm - 2M Ohm Variable Resistor 6mm | 1 | BOJACK | Amazon | $12.99
TAODAN PC817 Optocoupler | 50pcs DIP 2.54 mm Pitch 4-pin DIP-4 IC Chipset | 1 | TAODAN | Amazon | $5.98
 |  |  |  |  | $57.81

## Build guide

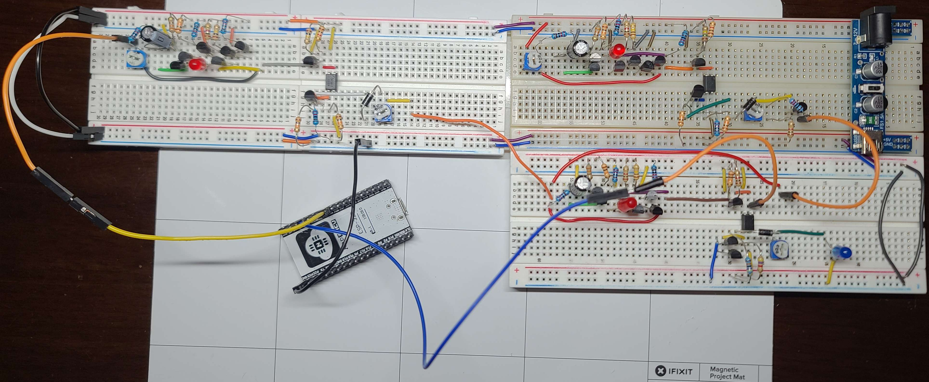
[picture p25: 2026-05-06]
docs/images/neural-network-game-setups/hit-the-zone-game-three-neuron-setup-breadboard-big.png

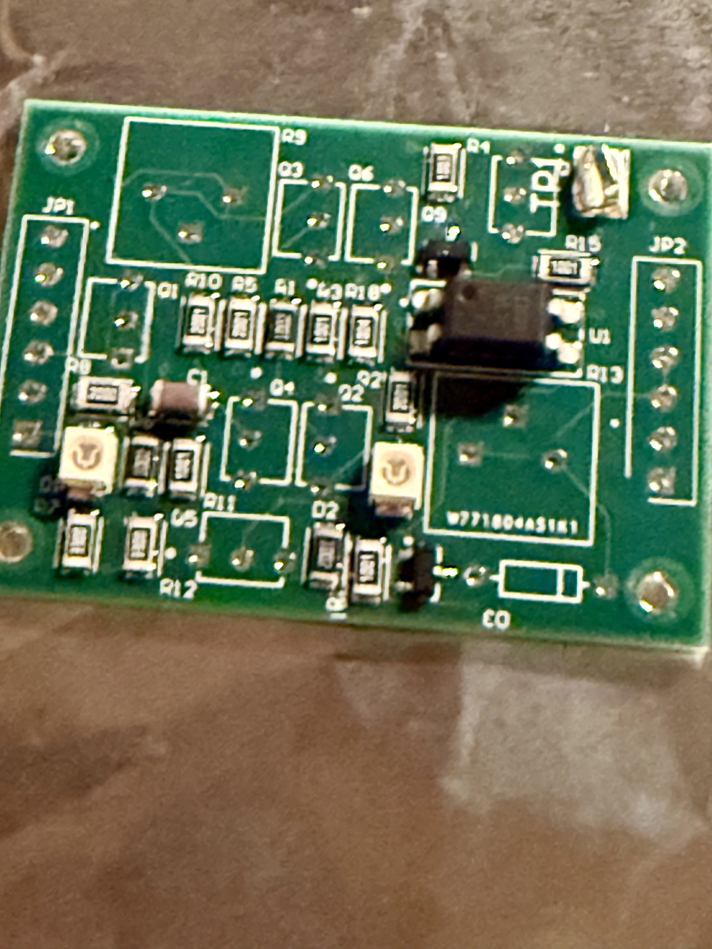
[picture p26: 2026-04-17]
hardware/pcb/PCB Soldering Images/PCB1.jpg

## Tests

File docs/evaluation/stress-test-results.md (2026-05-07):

# Stress Test Results

See also: [`tests/README.md`](../../tests/README.md) · [`docs/evaluation/coverage-report/README.md`](coverage-report/README.md)

### Test Configuration
- Tool: JUnit 5 stress suite with fake firmware/device support in `software/src/test/java/edu/sjsu/spring2026/group32/testsupport`
- Total Suite Runtime: 900 ms
- Virtual Users: Not applicable
- Target: Java hardware integration path
  - `SerialConnectionManager`
  - `HardwareSignalSource`
  - `NeuralSignalParser`
  - `NeuralHardwareConfig`
- Stress Scenarios:
  - Sustained mixed firmware traffic with valid samples, malformed lines, `STATUS`, `INFO?`, and injection commands
  - Random disconnect and reconnect recovery cycles
  - Signal burst, spike detection, and recovery after disconnect
  - Boundary and invalid-value sweeps for hardware configuration

### Results
| Metric | Value |
|---|---|
| Mixed Traffic Iterations | 750 |
| Disconnect/Reconnect Cycles | 10 |
| Signal Recovery Cycles | 12 |
| Passed Scenarios | 4 |
| Failed Scenarios | 0 |
| Total Stress Suite Runtime | 900 ms |

> The total suite runtime (900 ms) exceeds the sum of individual scenario runtimes (881 ms) by ~19 ms. This is normal JUnit framework overhead — test class initialization, JVM warmup between test classes, and test runner bookkeeping.

### Scenario Results
| Scenario | Result | Runtime | Notes |
|---|---|---|---|
| `serialConnectionManager_sustainedMixedFirmwareTraffic` | PASS | 31 ms | samples=750, malformed injected under mixed command traffic |
| `serialConnectionManager_randomDisconnectReconnectCycles` | PASS | 363 ms | cycles=10, seeded random burst traffic and full state reset checks |
| `neuralHardwareConfig_boundaryAndFailureSweep` | PASS | 1 ms | 25 boundary update rounds plus invalid voltage and speed rejection checks |
| `hardwareSignalSource_burstAndRecoveryStress` | PASS | 486 ms | cycles=12, repeated spike plateaus with reconnect recovery |

### Observations
- The stress suite is designed around firmware-style load rather than HTTP request load, so traditional response-time metrics are replaced by recovery, stability, and throughput-of-processing checks inside the Java runtime.
- The highest-value paths under stress are `hardware.serial` and `hardware.signal`, because those packages must tolerate malformed data, command churn, and connection instability without corrupting game state.
- The new suite specifically checks that disconnects clear `latestSampleFrame`, the next-line buffer (`getNextLine()`), device metadata, and signal state before reconnecting and resuming normal processing.
- The `hardware` package is also exercised through repeated boundary and invalid-value sweeps in `NeuralHardwareConfig`, which helps close a known low-coverage area.
- This measured run completed with 4 passing scenarios and 0 failures, so the simulated firmware path handled the current stress workload without instability.
- `hardwareSignalSource_burstAndRecoveryStress` was the slowest scenario at 486 ms, which makes sense because it includes asynchronous voltage propagation, spike detection, disconnect resets, and reconnect recovery in one loop.
- `serialConnectionManager_randomDisconnectReconnectCycles` was next at 363 ms, reflecting the cost of repeatedly tearing down and rebuilding serial state.
- `serialConnectionManager_sustainedMixedFirmwareTraffic` completed in 31 ms, which suggests the Java-side sample parsing and listener dispatch path is comfortably handling the current fake-firmware load volume.
- If failures appear, the first optimization targets should be:
  - serial read/recovery stability in `SerialConnectionManager`
  - listener state reset behavior in `HardwareSignalSource`
  - flaky wait timing in stress and lifecycle tests
  - any malformed-input parsing paths that create unnecessary exception overhead

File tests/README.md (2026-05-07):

# Tests

All tests for this project are written in Java using **JUnit 5 + Mockito** and live inside the Maven module, following the standard Maven source layout:

```
software/src/test/java/edu/sjsu/spring2026/group32/
├── bidirectionaltest/
│   └── core/               # Unit tests — ActiveDeviceVoltageInjector
├── hardware/
│   ├── serial/             # Unit tests — SerialConnectionManager
│   └── signal/             # Unit tests — NeuralSignalParser, HardwareSignalSource
├── hitthezone/             # Integration tests — HitTheZoneGame
│   ├── ai/                 # Unit tests — HitTheZoneSoftwareAI, HitTheZoneHardwareAI
│   ├── core/               # Unit tests — HitTheZoneEngine, HitTheZonePlayerFactory, HitTheZoneHardwareFactory
│   └── ui/                 # Unit tests — HitTheZoneControlPanel, HitTheZoneHudPanel, HitTheZoneInputController
├── launcher/               # Unit tests — Launcher bootstrap
│   ├── core/               # Unit tests — LauncherHardwareMessages, LauncherProgramRegistry
│   └── ui/                 # Unit tests — ConnectionStatusPanel, SerialConnectionPanel
├── player/                 # Unit tests — HumanPlayer, HardwareAIPlayer, PlayerType
├── pong/                   # Unit tests — PongAction, PlayerVariant, PongGame
│   ├── ai/                 # Unit tests — PongSoftwareAI, PongHardwareAI
│   ├── core/               # Unit tests — PongEngine, PongPlayerFactory, PongHardwareFactory, PongScoreboardService
│   └── ui/                 # Unit tests — PongInputController, PongPauseOverlay, PongToolbar, Scoreboard
├── stress/                 # Stress tests — SerialConnectionManager, HardwareSignalSource, NeuralSignalParser, NeuralHardwareConfig
└── testsupport/            # Shared test helpers — FakeSerialDevice, FakeSerialFirmware, SerialTestRig, MockitoHardwareSupport, TestSerialLines
```

**→ [Go to test source directory](../software/src/test/java/edu/sjsu/spring2026/group32)**

## Test Coverage

JaCoCo generates an HTML report at `software/target/site/jacoco/index.html` after `mvn verify`.
The latest report is also available as the **`jacoco-coverage-report`** artifact on every CI run.

**Current results:** 267 tests — 267 passed, 0 failed. Instruction coverage is **87%** (exceeding the 80% instruction target) and branch coverage is **76%** (exceeding the 70% core functionality target).

See [`docs/evaluation/coverage-report/README.md`](../docs/evaluation/coverage-report/README.md) for the full per-package breakdown, screenshots, and coverage target details.

## Stress Test Results

Documented in [`docs/evaluation/stress-test-results.md`](../docs/evaluation/stress-test-results.md).

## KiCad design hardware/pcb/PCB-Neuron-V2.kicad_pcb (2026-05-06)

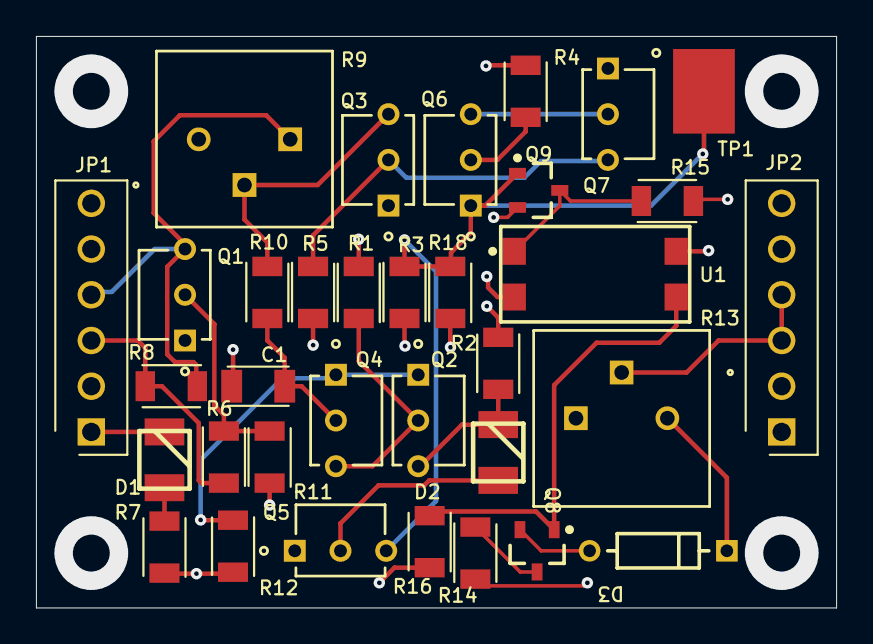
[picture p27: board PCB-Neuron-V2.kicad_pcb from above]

Board: 4 copper layers, 44.5 x 31.8 mm, 34 parts (0 on the bottom side), 22 nets.

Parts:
C1: C3216X5R1E476M160AC; C1206
D1, D2: AA3528SESK/J3; 2-PLCC-RED
D3: 1N4148WT; FP-017AG-MFG
JP1, JP2: HEADER_6X1; HEADER1x6PITCH100
Q1, Q2, Q3, Q4, Q5, Q6, Q7: 2n2222a; 2n2222a-Footprint-1
Q8, Q9: 2N7002
R1, R6, R16: RNCF1206TKY10K0; R1206
R2, R5, R10: ERJ-8ENF2001V; R1206
R3, R11, R14, R15: 1k; R1206
R4: 100k; R1206
R7, R12: 330; R1206
R8: ERJ-8ENF2000V; R1206
R9: Bourns 3386P-1-104LF; Bourns 3386P-1-104LF-Footprint-1
R13: 3386P-1-504LF; 3386P-1-504LF-Footprint-1
R18: ERJ-8ENF1004V; R1206
TP1: 5016
U1: LTV-817S; LTST-LTV-817S-4_V

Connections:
+3V3: D1.2, JP1.1, JP1.2, JP2.1, JP2.2, R1.2, R2.2, R3.2, R4.2, R5.2, R14.2, R15.2, U1.4
FB: Q3.3, R9.2, R10.1
G12_E: Q2.1, Q4.1, R12.2
G23_GA: D2.2, Q2.3, R2.1
G23_GK: D2.1, Q5.2
GND: C1.1, JP1.5, JP1.6, JP2.5, JP2.6, Q1.1, Q3.1, Q5.1, Q7.1, Q9.2, R7.1, R11.1, R12.1, R16.1, R18.1, U1.2
NetD1_1: D1.1, R7.2
NetJP1_3: JP1.3, R6.2, R8.2
NetJP1_4: JP1.4, Q1.3, R8.1, R9.3
NetJP2_3: JP2.3, JP2.4, R13.2
NetQ1_2: Q1.2, R6.1, R11.2
NetQ6_2: Q6.2, R4.1
Q1_G: C1.2, Q4.2, R10.2
Q7_D: Q9.3, R15.1, U1.1
Q8_D: Q8.3, R14.1
Q8_DK: D3.1, R13.1
Q8_S: D3.2, Q8.2
Q12_G: Q2.2, Q4.3, R1.1
Q34_G: Q5.3, Q6.1, Q9.1, R3.1, R18.2, TP1.1
Q45_CG: Q6.3, Q7.2
Q56_G: Q3.2, Q7.3, R5.1
U_Q8_G: Q8.1, R16.2, U1.3

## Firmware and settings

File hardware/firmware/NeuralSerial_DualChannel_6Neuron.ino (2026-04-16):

// ============================================================
//  NeuralSerial.ino — ESP32 Multi-Channel Neural Serial Firmware
//
//  Supports two hardware configurations selected at compile time
//  via CHANNEL_COUNT:
//
//  Config 1  (CHANNEL_COUNT 1) — 3-neuron / HitTheZone
//  ┌─────────────────────────────────────────────────────────┐
//  │ Micro USB  Java ↔ ESP32 @ 115200                       │
//  │ GPIO34 (ADC6)   Neuron output   → ADC read             │
//  │ GPIO25 (DAC1)   Neuron input    ← DAC drive (0–3.3 V)  │
//  │ GPIO2           LED threshold indicator (optional)      │
//  └─────────────────────────────────────────────────────────┘
//
//  Config 2  (CHANNEL_COUNT 2) — 6-neuron / Pong
//  ┌─────────────────────────────────────────────────────────┐
//  │ Micro USB  Java ↔ ESP32 @ 115200                       │
//  │ GPIO34 (ADC6)   Neuron 1 output → ADC read  (LEFT)     │
//  │ GPIO35 (ADC7)   Neuron 2 output → ADC read  (RIGHT)    │
//  │ GPIO25 (DAC1)   Neuron 1 input  ← DAC drive (LEFT)     │
//  │ GPIO26 (DAC2)   Neuron 2 input  ← DAC drive (RIGHT)    │
//  │ GPIO2           LED indicator (optional)                │
//  └─────────────────────────────────────────────────────────┘
//
// ── Upward stream  (ESP32 → Java, USB Serial @ 115200) ───────
//  Single channel:  "<millis>,1,0,<rawADC>"
//  Dual channel:    "<millis>,1,0,<rawADC1>,<rawADC2>"
//  Status messages: "STATUS,<event>[,<detail>]"
//
// ── Downward stream (Java → ESP32, USB Serial) ───────────────
//  INJECT_V:<v>         inject voltage on Ch 1 DAC (0.00–3.30 V)
//  INJECT_V_CH1:<v>     same as above (explicit)
//  INJECT_V_CH2:<v>     inject voltage on Ch 2 DAC (dual only)
//  INJECT:<raw>         inject raw DAC value on Ch 1 (0–4095)
//  INJECT_CH1:<raw>     same as above (explicit)
//  INJECT_CH2:<raw>     inject raw DAC value on Ch 2 (dual only)
//  STOP_INJECT          stop all injection, revert to real ADC
//  STOP_INJECT_CH1      stop Ch 1 injection only
//  STOP_INJECT_CH2      stop Ch 2 injection only (dual only)
//  STATUS               request a one-line status reply
// ============================================================

// ── Configuration ─────────────────────────────────────────────
//  Set CHANNEL_COUNT to 1 for 3-neuron HitTheZone config.
//  Set CHANNEL_COUNT to 2 for 6-neuron Pong config.
#define CHANNEL_COUNT 2

// ── Pin assignments ───────────────────────────────────────────
const int LED_PIN     = 2;

// ADC input pins (both are input-only on ESP32)
const int ADC_PIN_CH1 = 34;   // GPIO34 / ADC6 — always used
const int ADC_PIN_CH2 = 35;   // GPIO35 / ADC7 — dual only

// DAC output pins
const int DAC_PIN_CH1 = 25;   // GPIO25 / DAC1 — always used
const int DAC_PIN_CH2 = 26;   // GPIO26 / DAC2 — dual only

// ── Thresholds ────────────────────────────────────────────────
const int   LED_THRESHOLD_RAW = 1241; // ≈ 1.0 V  (1.0/3.3 * 4095)
const float V_MAX              = 3.3f;
const int   ADC_MAX            = 4095;
const int   DAC_MAX            = 255;  // ESP32 DAC is 8-bit

// ── Timing ────────────────────────────────────────────────────
const unsigned long LOOP_DELAY_MS = 10;

// ── Injection state (per channel) ────────────────────────────
bool injecting[2]   = {false, false};
int  injectedRaw[2] = {0, 0};

// ── Command buffer ────────────────────────────────────────────
String cmdBuffer = "";

// ── Helpers ───────────────────────────────────────────────────

/** Convert a raw ADC value (0–4095) to an 8-bit DAC value (0–255). */
inline int adcToDac(int rawAdc) {
    return constrain(rawAdc / 16, 0, DAC_MAX);
}

/** Convert a voltage (0.00–3.30 V) to an 8-bit DAC value. */
inline int voltsToDac(float v) {
    return constrain((int)((v / V_MAX) * DAC_MAX), 0, DAC_MAX);
}

/** Convert a voltage (0.00–3.30 V) to a 12-bit raw ADC equivalent. */
inline int voltsToRaw(float v) {
    return constrain((int)((v / V_MAX) * ADC_MAX), 0, ADC_MAX);
}

// ============================================================
void setup() {
    pinMode(LED_PIN, OUTPUT);

    // USB serial — communicates with Java
    Serial.begin(115200);
    Serial.println("STATUS,BOOT,NeuralSerial Ready,CH=" + String(CHANNEL_COUNT));
    Serial.println("#INFO:NeuralSignal,CH=" + String(CHANNEL_COUNT));
}

// ============================================================
void loop() {
    // 1. Process any commands from Java
    handleIncomingCommands();

    // 2. Read each active channel — always sample real hardware so that
    //    the serial stream and LED reflect the neuron's actual response,
    //    even while injection is driving the DAC input.
    int rawAdc[2];
    rawAdc[0] = analogRead(ADC_PIN_CH1);

#if CHANNEL_COUNT >= 2
    rawAdc[1] = analogRead(ADC_PIN_CH2);
#endif

    // 3. Drive DAC outputs (injection → DAC, else 0 V)
    dacWrite(DAC_PIN_CH1, injecting[0] ? adcToDac(injectedRaw[0]) : 0);

#if CHANNEL_COUNT >= 2
    dacWrite(DAC_PIN_CH2, injecting[1] ? adcToDac(injectedRaw[1]) : 0);
#endif

    // 4. LED: on when any active channel exceeds threshold
    bool ledOn = (rawAdc[0] > LED_THRESHOLD_RAW);
#if CHANNEL_COUNT >= 2
    ledOn = ledOn || (rawAdc[1] > LED_THRESHOLD_RAW);
#endif
    digitalWrite(LED_PIN, ledOn ? HIGH : LOW);

    // 5. Stream CSV to Java
    //    Single:  "<millis>,1,0,<raw1>"
    //    Dual:    "<millis>,1,0,<raw1>,<raw2>"
    String csv = String(millis()) + ",1,0," + String(rawAdc[0]);
#if CHANNEL_COUNT >= 2
    csv += "," + String(rawAdc[1]);
#endif
    Serial.println(csv);

    delay(LOOP_DELAY_MS);
}

// ============================================================
//  handleIncomingCommands
//  Non-blocking character accumulation — never stalls the loop.
// ============================================================
void handleIncomingCommands() {
    while (Serial.available() > 0) {
        char c = (char)Serial.read();
        if (c == '\n' || c == '\r') {
            if (cmdBuffer.length() > 0) {
                processCommand(cmdBuffer);
                cmdBuffer = "";
            }
        } else {
            cmdBuffer += c;
            if (cmdBuffer.length() > 64) cmdBuffer = "";  // overflow guard
        }
    }
}

// ============================================================
//  processCommand — parse and execute a single command string
// ============================================================
void processCommand(const String& cmd) {

    // ── INJECT_V:<volts>  or  INJECT_V_CH1:<volts> ──────────
    if (cmd.startsWith("INJECT_V_CH1:") || cmd.startsWith("INJECT_V:")) {
        int colon = cmd.indexOf(':');
        float v = constrain(cmd.substring(colon + 1).toFloat(), 0.0f, V_MAX);
        injectedRaw[0] = voltsToRaw(v);
        injecting[0]   = true;
        dacWrite(DAC_PIN_CH1, voltsToDac(v));
        Serial.println("STATUS,INJECT_START,CH1," +
                       String(injectedRaw[0]) + "," + String(v, 3) + "V");

    // ── INJECT_V_CH2:<volts>  (dual only) ───────────────────
    } else if (cmd.startsWith("INJECT_V_CH2:")) {
#if CHANNEL_COUNT >= 2
        float v = constrain(cmd.substring(13).toFloat(), 0.0f, V_MAX);
        injectedRaw[1] = voltsToRaw(v);
        injecting[1]   = true;
        dacWrite(DAC_PIN_CH2, voltsToDac(v));
        Serial.println("STATUS,INJECT_START,CH2," +
                       String(injectedRaw[1]) + "," + String(v, 3) + "V");
#else
        Serial.println("STATUS,ERR,CH2_NOT_AVAILABLE");
#endif

    // ── INJECT:<raw>  or  INJECT_CH1:<raw> ─────────────────
    } else if (cmd.startsWith("INJECT_CH1:") || cmd.startsWith("INJECT:")) {
        int colon = cmd.indexOf(':');
        int raw = constrain(cmd.substring(colon + 1).toInt(), 0, ADC_MAX);
        injectedRaw[0] = raw;
        injecting[0]   = true;
        dacWrite(DAC_PIN_CH1, adcToDac(raw));
        float v = (raw / (float)ADC_MAX) * V_MAX;
        Serial.println("STATUS,INJECT_START,CH1," + String(raw) + "," + String(v, 3) + "V");

    // ── INJECT_CH2:<raw>  (dual only) ───────────────────────
    } else if (cmd.startsWith("INJECT_CH2:")) {
#if CHANNEL_COUNT >= 2
        int raw = constrain(cmd.substring(11).toInt(), 0, ADC_MAX);
        injectedRaw[1] = raw;
        injecting[1]   = true;
        dacWrite(DAC_PIN_CH2, adcToDac(raw));
        float v = (raw / (float)ADC_MAX) * V_MAX;
        Serial.println("STATUS,INJECT_START,CH2," + String(raw) + "," + String(v, 3) + "V");
#else
        Serial.println("STATUS,ERR,CH2_NOT_AVAILABLE");
#endif

    // ── STOP_INJECT  (all channels) ─────────────────────────
    } else if (cmd == "STOP_INJECT") {
        injecting[0] = false;
        injecting[1] = false;
        dacWrite(DAC_PIN_CH1, 0);
#if CHANNEL_COUNT >= 2
        dacWrite(DAC_PIN_CH2, 0);
#endif
        Serial.println("STATUS,INJECT_STOPPED,ALL");

    // ── STOP_INJECT_CH1 ─────────────────────────────────────
    } else if (cmd == "STOP_INJECT_CH1") {
        injecting[0] = false;
        dacWrite(DAC_PIN_CH1, 0);
        Serial.println("STATUS,INJECT_STOPPED,CH1");

    // ── STOP_INJECT_CH2  (dual only) ────────────────────────
    } else if (cmd == "STOP_INJECT_CH2") {
#if CHANNEL_COUNT >= 2
        injecting[1] = false;
        dacWrite(DAC_PIN_CH2, 0);
        Serial.println("STATUS,INJECT_STOPPED,CH2");
#else
        Serial.println("STATUS,ERR,CH2_NOT_AVAILABLE");
#endif

    // ── STATUS ───────────────────────────────────────────────
    } else if (cmd == "STATUS") {
        String mode0 = injecting[0] ? "INJECTING" : "NORMAL";
        float  v0    = (injectedRaw[0] / (float)ADC_MAX) * V_MAX;
        String reply = "STATUS,OK,CH=" + String(CHANNEL_COUNT) +
                       ",CH1=" + mode0 +
                       "," + String(injectedRaw[0]) +
                       "," + String(v0, 3) + "V";
#if CHANNEL_COUNT >= 2
        String mode1 = injecting[1] ? "INJECTING" : "NORMAL";
        float  v1    = (injectedRaw[1] / (float)ADC_MAX) * V_MAX;
        reply += ",CH2=" + mode1 +
                 "," + String(injectedRaw[1]) +
                 "," + String(v1, 3) + "V";
#endif
        Serial.println(reply);

    // ── INFO? : respond with device capabilities ─────────────────
    } else if (cmd == "INFO?") {
        Serial.println("#INFO:NeuralSignal,CH=" + String(CHANNEL_COUNT));

    // ── Unknown command ──────────────────────────────────────
    } else {
        Serial.println("STATUS,UNKNOWN_CMD," + cmd);
    }
}

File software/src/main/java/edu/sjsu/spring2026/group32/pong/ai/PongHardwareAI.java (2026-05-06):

package edu.sjsu.spring2026.group32.pong.ai;

import edu.sjsu.spring2026.group32.hardware.signal.BaseSignalSource;
import edu.sjsu.spring2026.group32.hardware.signal.HardwareSignalSource;
import edu.sjsu.spring2026.group32.hardware.NeuralHardwareConfig;
import edu.sjsu.spring2026.group32.hardware.signal.VoltageInjector;
import edu.sjsu.spring2026.group32.player.model.BasePlayer;
import edu.sjsu.spring2026.group32.player.model.PlayerType;
import edu.sjsu.spring2026.group32.pong.model.PongAction;
import edu.sjsu.spring2026.group32.pong.core.PongEngine;
import edu.sjsu.spring2026.group32.pong.model.PongState;

import java.util.concurrent.atomic.AtomicInteger;

/**
 * Hardware AI player for vertical Pong.
 *
 * <h3>Dual-channel 6-neuron firmware (NeuralSerial_DualChannel_6Neuron)</h3>
 * <ul>
 *   <li>Channel 1 (GPIO34 / DAC1) — left 3-neuron group: controls LEFT movement</li>
 *   <li>Channel 2 (GPIO35 / DAC2) — right 3-neuron group: controls RIGHT movement</li>
 * </ul>
 *
 * <h3>Injection strategy</h3>
 * <p>On every game tick {@link #getNextMove} first checks whether the ball is
 * moving <em>toward</em> the hardware player (negative {@code ballVelY}).
 * Injection is suppressed entirely while the ball travels away; any active
 * channel is stopped at that transition.  When the ball is incoming, the
 * offset between the ball's X position and the paddle center determines which
 * channel to drive: more than {@link #DEAD_ZONE} pixels to the left → CH1
 * (left neurons); to the right → CH2 (right neurons).  When crossing sides
 * the previous channel is explicitly stopped before the new one is started
 * (per the firmware's {@code STOP_INJECT_CHn} / {@code INJECT_V_CHn}
 * protocol).  Within the dead zone both channels are stopped so the paddle
 * coasts.
 *
 * <h3>Action mapping</h3>
 * <p>After updating injection, the ADC readings are sampled:
 * CH1 voltage ≥ threshold → {@link PongAction#LEFT},
 * CH2 voltage ≥ threshold → {@link PongAction#RIGHT},
 * otherwise → {@link PongAction#IDLE}.
 * If both channels fire simultaneously LEFT takes precedence.
 *
 * <h3>Wiring example (in Launcher / PongGame)</h3>
 * <pre>{@code
 *   NeuralSignalParser  p0         = new NeuralSignalParser(0);   // CH1 = GPIO34 = LEFT
 *   NeuralSignalParser  p1         = new NeuralSignalParser(1);   // CH2 = GPIO35 = RIGHT
 *   HardwareSignalSource leftSrc   = new HardwareSignalSource(pongManager, p0);
 *   HardwareSignalSource rightSrc  = new HardwareSignalSource(pongManager, p1);
 *   PongHardwareAI hw = new PongHardwareAI("Hardware", leftSrc, rightSrc, leftSrc);
 * }</pre>
 * {@code leftSrc} is passed as the {@link VoltageInjector} because
 * {@link HardwareSignalSource} implements both interfaces and both sources
 * share the same serial connection, so either can send injection commands.
 */
public class PongHardwareAI implements BasePlayer<PongState, PongAction> {

    /**
     * Half-width dead zone around the paddle center (pixels).
     * Derived from paddle width so the hardware player stops injecting when
     * the ball is already close enough that no correction is needed.
     * {@code PADDLE_WIDTH / 4} = 20 px at the default 80 px paddle width.
     */
    private static final int DEAD_ZONE = PongEngine.PADDLE_WIDTH / 4;

    /** Tracks which channel is currently being injected to avoid redundant serial commands. */
    private enum InjectState { NONE, LEFT, RIGHT }

    private final String           name;
    private final BaseSignalSource leftSource;
    private final BaseSignalSource rightSource;
    private final VoltageInjector  injector;
    private final double           leftThreshold;
    private final double           rightThreshold;
    private final double           leftInjectionVoltage;
    private final double           rightInjectionVoltage;

    private InjectState lastInject       = InjectState.NONE;

    /**
     * Guards all injection calls.  {@code false} by default — injection only
     * starts once the HARDWARE variant is explicitly selected in the game UI.
     * Set via {@link #setInjectionEnabled(boolean)}.
     */
    public volatile boolean injectionEnabled = false;

    /**
     * Total spike events detected since the last reset (both channels combined).
     * Incremented each game tick a channel's voltage meets or exceeds the
     * firing threshold.  Reset via {@link #resetSpikeCount()}.
     * AtomicInteger is used because {@code ++} on a volatile int is not atomic.
     */
    private final AtomicInteger spikeCount    = new AtomicInteger(0);

    /** Spike events from Channel 1 (left source) since the last reset. */
    private final AtomicInteger ch1SpikeCount = new AtomicInteger(0);

    /** Spike events from Channel 2 (right source) since the last reset. */
    private final AtomicInteger ch2SpikeCount = new AtomicInteger(0);

    // =========================================================================
    // Constructors
    // =========================================================================

    /**
     * Full constructor.
     *
     * @param name        display name shown in scoreboard and overlays
     * @param leftSource  ADC signal source for LEFT movement (CH1 / GPIO34)
     * @param rightSource ADC signal source for RIGHT movement (CH2 / GPIO35)
     * @param injector    used to send {@code INJECT_V_CHn} / {@code STOP_INJECT_CHn}
     *                    commands to the ESP32; pass {@link VoltageInjector#NONE}
     *                    for software-only runs or unit tests
     * @param threshold   voltage at or above which a direction fires (0.0–3.3 V)
     */
    public PongHardwareAI(String name,
                          BaseSignalSource leftSource,
                          BaseSignalSource rightSource,
                          VoltageInjector injector,
                          double leftInjectionVoltage,
                          double rightInjectionVoltage,
                          double leftThreshold,
                          double rightThreshold) {
        this.name = name;
        this.leftSource = leftSource;
        this.rightSource = rightSource;
        this.injector = injector;
        this.leftInjectionVoltage = leftInjectionVoltage;
        this.rightInjectionVoltage = rightInjectionVoltage;
        this.leftThreshold = leftThreshold;
        this.rightThreshold = rightThreshold;
    }
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

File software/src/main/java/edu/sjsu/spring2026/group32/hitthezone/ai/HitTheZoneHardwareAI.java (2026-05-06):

package edu.sjsu.spring2026.group32.hitthezone.ai;

import edu.sjsu.spring2026.group32.hardware.signal.BaseSignalSource;
import edu.sjsu.spring2026.group32.hardware.NeuralHardwareConfig;
import edu.sjsu.spring2026.group32.hardware.signal.VoltageInjector;
import edu.sjsu.spring2026.group32.player.HardwareAIPlayer;
import edu.sjsu.spring2026.group32.hitthezone.model.HitTheZoneAction;
import edu.sjsu.spring2026.group32.hitthezone.model.HitTheZoneState;

/**
 * Hardware AI player for the Hit The Zone proof-of-concept game.
 *
 * <h3>Voltage injection (ball in zone)</h3>
 * <p>On every zone <em>entry</em> this player sends a constant
 * {@link NeuralHardwareConfig#DEFAULT_HIT_THE_ZONE_INJECTION_VOLTAGE} stimulus to the neural hardware via its
 * {@link VoltageInjector}. On every zone <em>exit</em> it sends a stop
 * command so the hardware reverts to normal ADC sampling. This keeps
 * all serial-protocol knowledge inside the hardware player and away from
 * the game loop.
 *
 * <h3>Spike reading</h3>
 * <p>Returns {@link HitTheZoneAction#SCORE} on the rising edge of a spike:
 * the first in-zone tick where voltage crosses from below to at-or-above
 * {@code voltageThreshold}. Subsequent high-voltage ticks from the same spike
 * return {@code null} until the signal falls back below the threshold.
 *
 * <h3>Threshold choice</h3>
 * <p>The default threshold is shared through
 * {@link NeuralHardwareConfig#DEFAULT_FIRING_THRESHOLD_VOLTS} so
 * hardware-backed games use the same firing baseline unless they
 * explicitly override it.
 */
public class HitTheZoneHardwareAI
        extends HardwareAIPlayer<HitTheZoneState, HitTheZoneAction> {
    private static final String ANSI_GREEN = "\u001B[32m";
    private static final String ANSI_RESET = "\u001B[0m";
    private static final double LOGGED_VOLTAGE_MIN = 0.85;

    private final VoltageInjector injector;
    private final double injectionVoltage;
    private final double voltageThreshold;

    /** Tracks the zone state from the previous tick to detect entry/exit edges. */
    private boolean wasInZone = false;

    /**
     * Canonical constructor.
     *
     * @param name display name shown in the game HUD
     * @param signalSource voltage source (real serial hardware or a test stub)
     * @param injector used to send inject/stop commands to the ESP32;
     *                 pass {@link VoltageInjector#NONE} for software-only runs
     * @param voltageThreshold minimum voltage required to register a SCORE (volts)
     */
    public HitTheZoneHardwareAI(String name,
                                BaseSignalSource signalSource,
                                VoltageInjector injector,
                                double injectionVoltage,
                                double voltageThreshold) {
        super(name, signalSource);
        this.injector = injector;
        this.injectionVoltage = injectionVoltage;
        this.voltageThreshold = voltageThreshold;
    }

    private void debug(String message) {
        System.out.printf("[HTZ-AI %s] %s%n", getName(), message);
    }

    private void debugGreen(String message) {
        System.out.printf(ANSI_GREEN + "[HTZ-AI %s] %s" + ANSI_RESET + "%n", getName(), message);
    }

    private void updateInjectionForZoneTransition(HitTheZoneState state) {
        if (!wasInZone && state.inZone()) {
            debug(String.format("zone enter -> inject %.3fV", injectionVoltage));
            injector.injectVoltage(injectionVoltage);
        } else if (wasInZone && !state.inZone()) {
            debug("zone exit -> stop injection");
            injector.stopInjection();
            // Voltage returns to 0 after injection stops, which naturally resets
            // the parser's lastWasAbove flag before the next zone entry.
        }
        wasInZone = state.inZone();
    }

    private HitTheZoneAction actionFromVoltage(HitTheZoneState state, double voltage) {
        if (!state.inZone()) {
            // Late-fire contract: a genuine new spike (rising edge) that occurs after
            // zone exit still registers a SCORE event.  Using sourceHasSpike() here —
            // rather than a stateless voltage comparison — prevents the plateau of a
            // spike already counted in-zone from spilling over into a spurious out-of-zone
            // attempt when the ball exits while voltage is still high.  Without this,
            // every in-zone hit produces one extra uncredited processScore() call,
            // inflating the attempts counter and halving the displayed accuracy.
            if (sourceHasSpike(voltageThreshold)) {
                debug(String.format("score %.3fV (late-fire, out of zone)", voltage));
                return HitTheZoneAction.SCORE;
            }
            return null;
        }
        if (voltage >= LOGGED_VOLTAGE_MIN) {
            debug(String.format("in-zone voltage %.3fV (threshold %.3fV)", voltage, voltageThreshold));
        }
        // Rising-edge detection is delegated to NeuralSignalParser.hasSpike() via
        // HardwareAIPlayer.sourceHasSpike().  A multi-tick spike plateau produces
        // exactly one SCORE instead of one per game tick.
        if (sourceHasSpike(voltageThreshold)) {
            debugGreen(String.format("emit SCORE at %.3fV", voltage));
            return HitTheZoneAction.SCORE;
        }
        return null;
    }

    /**
     * Convenience constructor using the shared default threshold.
     *
     * @param name display name shown in the game HUD
     * @param signalSource voltage source (real serial hardware or a test stub)
     * @param injector used to send inject/stop commands to the ESP32
     */
    public HitTheZoneHardwareAI(String name,
                                BaseSignalSource signalSource,
                                VoltageInjector injector) {
        this(
                name,
                signalSource,
                injector,
                NeuralHardwareConfig.DEFAULT_HIT_THE_ZONE_INJECTION_VOLTAGE,
                NeuralHardwareConfig.DEFAULT_FIRING_THRESHOLD_VOLTS);
    }

    /**
     * Convenience constructor with no injection and a custom threshold.
     *
     * @param name display name shown in the game HUD
     * @param signalSource voltage source (real serial hardware or a test stub)
     * @param voltageThreshold minimum voltage required to register a SCORE (volts)
     */
    public HitTheZoneHardwareAI(String name,
                                BaseSignalSource signalSource,
                                double voltageThreshold) {
        this(
                name,
                signalSource,
                VoltageInjector.NONE,
                NeuralHardwareConfig.DEFAULT_HIT_THE_ZONE_INJECTION_VOLTAGE,
                voltageThreshold);
    }
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

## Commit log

2026-03-11 Refactor PoC (move to own SRC folder). Add new features.
    Keybind controls.
    Continuous play.
    Running total with accuracy %.
    Reset button.
2026-03-15 Implement SerialConnectionManager to manage serial devices
2026-03-15 Implement NeuralSignalParser to convert ADC to voltage
2026-03-18 Implement testValidDataParsing() to verify standard CSV line parses the correct voltage
2026-03-18 Implement testAdcBounds() to verify max ADC value maps to 3.3V and min ADC val maps to 0.0V
2026-03-19 Implement setUp() to reinitialize NeuralSignalParser before each test to prevent voltage history leaks
2026-03-19 Implement testMissingHardwareHandling() to verify correct handling when the hardware connection fails
    [HardwareSignalSourceTest.java]
2026-03-19 Fix testMissingHardwareHandling() to verify connect() is called twice to account for reconnection attempt
    [HardwareSignalSourceTest.java]
2026-03-19 Implement testNoCompatibleHardware() to verify connect() returns false and getNextLine() returns null when no device is found
2026-03-23 More closely matches physical circuit values
2026-03-28 Create BidirectionalTest.ino ESP32 firmware for testing bidirectional communication
2026-03-28 Create BidirectionalTest.java program for testing bidirectional communication and voltage injection
2026-04-08 Add files via upload
    Fixed issue with MOSFET (M1)
2026-04-12 Upload ESP32 firmware for 3 neuron (single-channel) and 6 neuron (dual-channel) config
2026-04-12 Update voltage injection to support dual channel in BidirectionalTest.java
2026-04-14 Switch to two row layout for COMM connection in Launcher
2026-04-14 Update BidirectionalTest to support voltage injection on both channels and update display logic
2026-04-16 MOSFET rewiring
2026-04-16 BidirectionalTest: Fix UI bugs in pause logic
    [BidirectionalTest.java]
2026-04-16 Read raw voltage only. Remove software test artifacts from firmware.
2026-04-17 Physical PCB images/progress
2026-04-18 Bodging new wires
2026-04-18 updated pcb & sch files
    original PCB design schematic and board had mosfet inverted
    [NeuronSynapseVersion7(kicad_sch).kicad_sch, PCB2.kicad_pcb]
2026-04-18 Implement Player Variant Switch test
2026-04-20 Rename Synapses.csv to PCB BOM
2026-04-22 Rename PCB BOM to PCB BOM.csv
    [PCB BOM.csv]
2026-04-24 Add VoltageInjector class
2026-04-24 Fix bug where bidirectionaltest disconnects COMM device after shutdown
    [BidirectionalTest.java]
2026-04-24 Fix voltage injection bug where injection continues after closing a program
    [BidirectionalTest.java, HitTheZoneHardwareAI.java, HitTheZoneHardwareAITest.java]
2026-04-24 Disable EMA config (pass raw voltage)
2026-04-24 Move threshold voltage to shared NeuralHardwareConfig class
2026-04-30 Enhance Voltage Graph with Autoscaling Y-Axis. Live Reading text enhancements.
2026-04-30 UI/UX enhancements in navigation for bidirectionaltest voltage injection panels
2026-04-30 Launcher: Add channel count check when connecting ESP32s
2026-04-30 Launcher: Warning popup for unsupported USB devices
2026-05-01 Rework spike detection for HitTheZone and PongGame
    [HardwareSignalSourceTest.java, HitTheZoneHardwareAI.java, HitTheZoneHardwareAITest.java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]
2026-05-01 HitTheZone: Fix bug on voltage injection while paused
2026-05-01 BidirectionalTest - Fix bug with voltage injector panel flickering
    [BidirectionalTest.java]
2026-05-01 Launcher: Update SerialConnectionPanel UI to be more descriptive. Force disconnect for wrong devices.
2026-05-01 Disable voltage injection logs. Refactor Launcher (text, behavior on window height change)..
2026-05-01 Launcher: Add advanced settings (voltage injection, threshold) for COMM ports
2026-05-03 Remove stale test files that failed to compile after refactor
    [PongHardwareAITest.java]
2026-05-05 Organize hardware/schematics directory
2026-05-05 Add ESP32 datasheet and pin-out diagram
2026-05-05 Organize hardware/pcb folder. Move Kicad Schematic to hardware/schematics.
    [Neuron-Synapse-Version7-Kicad-Schematic.kicad_sch, NeuronSynapseVersion3 (1).SchDoc, NeuronSynapseVersion7(kicad_sch).kicad_sch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]
2026-05-05 In docs, add pcb-neuron-3D-render. Reorganize docs/images directory
2026-05-06 Update README.md with more diagrams and explanations
    Update README.md project structure to be in-order
    Add Single Neuron V1 Schematic
    Update README.md introduction paragraph
    Add Pong SNN diagram to README.md
    Move Spring 2026 Project Roster link at the bottom in README.md
    Move Configuration near Running the Application in README.md
    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
2026-05-07 README.md: Major enhancements to instructions + tweaks + references
    Add extra link to SJSU Spring 2026 CMPE Project Expo
    Update README.md to be more consistent and correct.
    Rewrite breadboard and PCB assembly instructions with more detail.
    Add references to external datasheets and diagrams
2026-05-07 Added BOM for the breadboard prototype
    [BOM_breadboard.csv]
2026-05-07 Update README.md with new BOM + fix table formats and project structure spacing
    Update README.md with new BOM
    Fix table formats in README.md
    Fix spacing in Project Structure section in README.md
    [BOM_pcb.csv, PCB BOM.csv]
